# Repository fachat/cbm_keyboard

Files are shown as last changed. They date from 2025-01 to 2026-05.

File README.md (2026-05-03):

# Commodore PET keyboards

Note: this is a part of a larger set of repositories, with [upet_family](https://github.com/fachat/upet_family) as the main repository.

This is part of a re-incarnation of the Commodore PET computer(s) from the later 1970s.

This repo shows how to build a keyboard for the Commodore PET, mainly for my own re-incarnation, but potentially for original PET as well (untested).

Keyboards can be seen in the PETindex [keyboard section](http://www.6502.org/users/andre/petindex/keyboards.html).

## N-Type

This keyboard is the typewriter-stlye keyboard used in most 40 column models, except for the originals with the chicklet keyboard.

### PCB

#### Open source PCB by Steve Gray

For my builds I started by using the N-type keyboard PCB by Steve Gray from his [MX replacement keyboards projects](http://cbmsteve.ca/mxkeyboards/index.html)
As Steve only has the PCB, I designed a 3D-printable base support for the PCB.
It is available on tinkercad and the STL files are also available here.

Based on that I created a new R3 version of the board that includes options for
backlit LEDs and keyboard controllers allowing key re-mapping independent from
the PET's own editor ROM. You can find it in [PET-N](PET-N)

NOTE: In R3.0A you need to fix some things:

1. Connect the V33 and VCC33 lines - basically the oscillator for the Atmega controllers does not have power, so that needs to be supplied.
2. There is an off-by-one error on the row multiplexer. It has rows R0-9, while the keys are connected to R1-10. For now you have to connect R0 and R10, and fix the issue in the controller software.

In the current R3.0B these two fixes have been applied, but the actual PCB is not tested yet (and probably never will). A future 3.1 fix this for good.

### Programming the R3 PCB

The R3 PCB has (optionally) two Atmega32a microcontrollers on board, that implement two functions:

1. mapping keys between the keyboard and the host 
2. controlling the LEDs.

To program the Microcontrollers you need an AVR programming tool like the AVRisp MkII that I use, or similar, that can program via the SPI interface (plus Reset) on the 6 pin programming header (which exists separately for each of the two Microcontrollers)

Both microcontrollers are connected to the I2C bus on the extended UPET keyboard interface.

#### Functions of the keyboard controller

Currently the keyboard controller maps the keys 1:1 from the keyboard matrix to the host keyboard interface.

In addition it sends the pressed keys (hardware key index) via I2C to address 0x10 (which is the LED controller).

Also, the keyboard mapping has these options:

1. direct mapping - each key is directly mapped to the corresponding host key
2. The top row of characters is remapped from the PET-N's characters (like $, %, etc) to the digits you'd normally expect in this place. The original chars are available with Shift, the originally shifted characters are available with Ctrl.

Note that in the future more mappings may be implemented.

Selection of the mapping is done by pressing the SRQ key a few seconds long. The keyboard will then send a menu text to the host that instructs the user how to switch the mapping.
It is best if the menu is triggered e.g. on the BASIC prompt.

The mapping is stored in the Atmega's EEPROM, and thus retained when the machine is switched off.

#### Functions of the LED controller

The LED controller listens on the I2C address 0x10 for commands.

With these commands you can set the constant value of each key LED, but also trigger certain programs that involve either a single key, or multiple keys.
For single keys you can let the colour slowly get dimmer until the LED is off, and then optionally restart with the original value.

The DILUTE program tries to do a simulated flow of the colour from the given key to the surrounding keys. It is not as good and smooth as it could be as the 
Atmega lacks memory to store the required precision of colour values.

The LOGO just sends the logo onto the keypad, and then lets it decay.

```
        // single LED programs. Followed by index, three colours, and a parameter
        LP_CONST        = 0,    // constant value, using the three parameters as RGB
        LP_LINDECAY     = 1,    // linear decay (note may change hue while getting lower)
        LP_LINDECAYLOOP = 2,    // linear decay with restart

        // single command program
        SP_KEYPRESS     = 64,   // just followed by the index to indicate a pressed key

        // multi-key programs
        KP_DILUTE       = 128,  // set initial value to given params, then let it flow off 
        KP_LOGO         = 129,  // C= logo on the keypad
```

All commands except KEYPRESS expect the key index, three colours, and a parameter after the command, i.e. six bytes in total.
KEYPRESS only has the index and thus requires only two bytes.

### Supports for PCB

The PCB needs some kind of support to be mounted into the PET or the Ulti-/Micro-PET cases.
There are two versions for Steve's and my derived PCB, the first one for the extended
that caters for the different connector, and the one better suitable for the original
PCB.

* [New support structure extended PET-N keyboard](https://www.tinkercad.com/things/2KwSQVdno7K-sjg-keybd-full-support-r1)
* [left part of the support](PET-Keyboard-Support-SJG-N-R1-left.stl)
* [right part of the support](PET-Keyboard-Support-SJG-N-R1-right.stl)

* [support structure for Steve's N-type keyboard at tinkercad](https://www.tinkercad.com/things/cUVlushPB3j-sjg-keybd-full-support-v07).
* [left part of the support](PET-Keyboard-Support-SJG-N-v07-left.stl)
* [right part of the support](PET-Keyboard-Support-SJG-N-v07-right.stl)

#### Texelec Petskey keyboard

This is the PET N-type keyboard available from Texelec.

As this is the PCB only, I have created a support structure for this too. Note, however, as I now prefer Steve's PCB, I only have an old version of the supports on tinkercad.

Two of each of these supports make up a keyboard base plate, where you only need to clip in the PCB for the keyboard with the mounted key switches. Then they have about the same dimensions as a C64 keyboard, and you can use them on top of the C64 keyboard support stands.

* [Petskey 1.0 keyboard on Texelec](https://texelec.com/product/petskey/)
* [Petskey support on tinkercad](https://www.tinkercad.com/things/5lenSoehSRu-petskey-full-support-plate)

### Key caps

There are two options, either use standard key caps, or 3D-printed ones.

#### Standard Keycaps

As, for the self-built keyboards from option 1 or 2 some standard MX switches are used, standard
key caps can be used as well. There is one caveat, however.

Newer key caps typically have a different inclination for each row of keys, that is the angle of the top key surface against the horizontal
is different for each row. This is to facilitate easier typing. In fact even the C64 keyboard has this.
The old PET keyboards, however, have the same angle - which is not zero! - for all rows. This makes it easier to use the same cap (in terms of physical dimensions)
on all rows, and just print on a different character for each key. Read more on those [key profiles](https://switchandclick.com/sa-vs-dsa-vs-oem-vs-cherry-vs-xda-keycap-profiles/).

I used two type of standard key caps:

1. [XDA profile, unmarked](https://www.amazon.de/gp/product/B06XSHK528/): this set of key caps does not have a print on it, and all keys have the same angle - zero. So it is
possible to use any of the key caps in any row. Which is important, as you need a specific number of keys for each key width.
Also, this set has space bars in different lengths, and there is one that fits the 6.25 character wide space bar for the petskey and sjg keyboards.
For the markings I just used a pen...

2. This one [Glorious PC Gaming Race ABS Doubleshot black, ANSI layout GAKC-045](https://www.caseking.de/glorious-pc-gaming-race-abs-doubleshot-schwarz-ansi-us-layout-gakc-045.html) I actually bought more or less
by accident. I only noticed that it has different angles per row when I tried it out. However, with the amount of caps I was able to only
use a wrong angle on Shift Lock, left Shift, Return and "4" - but it's barely noticable.
For the markings I used template from Steve's page, printed it on sticky paper, cut it out and glued it on the keys where the original did not fit.

#### Printed Keycaps

As a third option I used 3-D printed key caps that I designed myself.

The keycaps are made of three parts each:
1) a key form created by a parametric generator,
2) the top character print, extruded from the key form,
3) the front character (mostly the shifted character), extruded from the key form.

I created all parts, and integrated them in the [Tinkercad](https://tinkercad.com) web tool.

The key form is created using OpenSCAD by a [parametric generator](https://www.thingiverse.com/thing:2783650) (by Thingieverse user rsheldiii, published under the [CC BY-SA 3.0](https://creativecommons.org/licenses/by-sa/3.0/) license). Here is the [parameter file](keycaps/key_cbm3_customizer.scad). Only the key width needs to be adapted, and the inversion of the top for the space key.

Most of the top character prints are made from a [Microgramm font](https://www.wfonts.com/font/microgramma), converted to SVG using the [Font Squirrel](https://www.fontsquirrel.com/tools/webfont-generator) web page.

Some top characters, and especially the top words ("SHIFT", "RUN STOP" etc) are taken from [Steve's github page](https://github.com/sjgray/CBM-MX-Keyboards/tree/master/stickers). As SVG exported from inkscape did not work when imported
into tinkercad, I had to make screenshots from each character, and convert these screenshots into SVGs using this [online converter](https://image.online-convert.com/convert-to-svg).

The front characters are all from an [SVG file from wikipedia](https://en.wikipedia.org/wiki/Commodore_PET#/media/File:PET_Keyboard_improved.svg), from which I also took screenshots and converted to SVG as above.

You can find an oder version of the the STL files [here](keycaps/), in four parts due to its size. The current version is linked from tinkercad below.
Please note that it took me about 100+ hours just to print the full set of keys on my Snapmaker printer in high quality.
After printing you have to remove the supports that anchor the stem to the outside of the keycaps so it does
not break away when printing.

For your convenience there is an open project at PCBWay to print the key caps, see the links.

* [Keycaps for resin printing](https://www.tinkercad.com/things/7a94wJbLJPW-commodore-pet-caps-for-n-type-ulti-keyboard-resin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)
* [Master file for keycaps](https://www.tinkercad.com/things/clKxMCUccgg-master-commodore-pet-caps-for-n-ulti-keyboard-support-cuts)
[//] # * [Open project at PCBWay 3D printing](https://www.pcbway.com/project/shareproject/Commodore_PET_N_type_keycaps_c1c2d1a0.html)

### Switches

The PCBs work with standard Cherry-type/-compatible switches. I only tested Cherry brand switches, though. You may select depending on your preference regarding force needed, click noise etc.

I found the MX1A-C1NW a good compromise for me.

* [Cherry MX1A-C1NW at Mouser](https://www.mouser.de/ProductDetail/540-MX1A-C1NW)

## Gallery

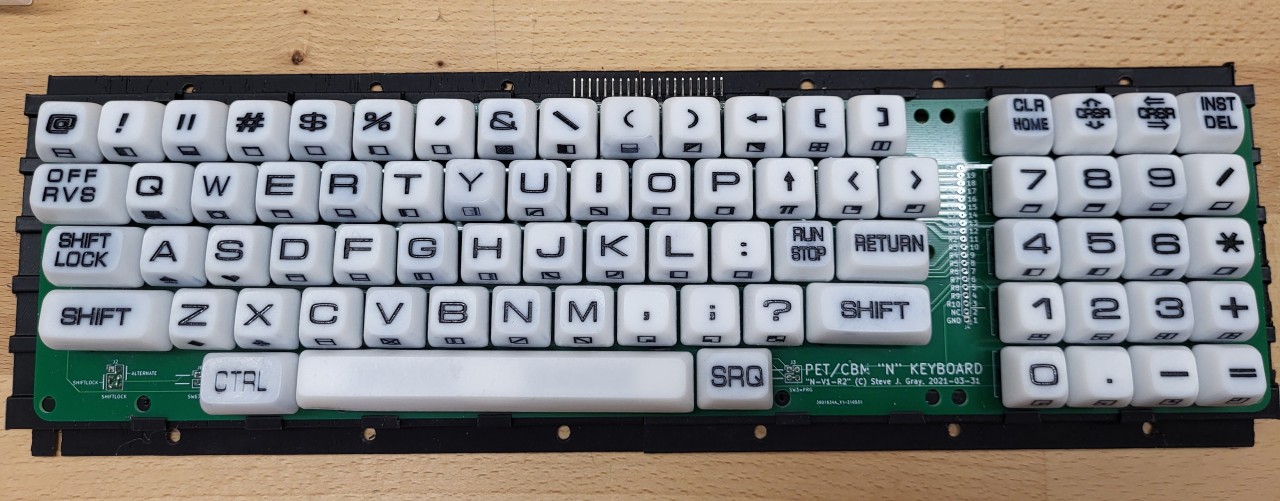
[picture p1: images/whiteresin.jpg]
Assembled keyboard with white resin printed caps
 Assembled keyboard with white resin printed caps, with key prints painted with black alcohol ink
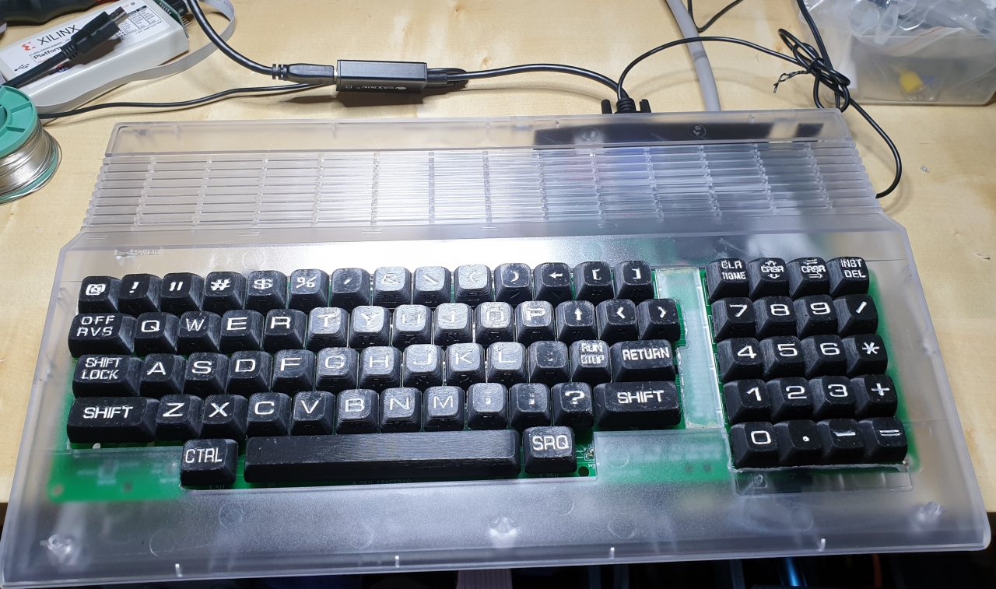
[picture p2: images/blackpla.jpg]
Assembled keyboard with black PLA printed caps
 Assembled keyboard with black PLA printed caps, with key prints painted with white alcohol ink
Assembled keyboard with black PLA printed caps Assembled keyboard with black PLA printed caps

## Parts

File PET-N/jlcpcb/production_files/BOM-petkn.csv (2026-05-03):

Comment | Designator | Footprint | LCSC | Quantity
100n | C10,C11,C12,C13,C14,C17,C30,C31,C7,C8,C9 | C_0805_2012Metric_Pad1.18x1.45mm_HandSolder | C14663 | 11
100u | C1,C15,C16,C18,C19,C2,C20,C21,C22,C23,C24,C25,C26,C27,C28,C29,C3,C32,C33,C4,C5,C6 | C_1206_3216Metric_Pad1.33x1.80mm_HandSolder | C15008 | 22
10k | R3,R4,R5 | R_0603_1608Metric | C25804 | 3
LSF0204Q | U1 | TSSOP-14_4.4x5mm_P0.65mm | C2677502 | 1
~ | U5 | THB Miniature Thumbstick THB001P | C2685355 | 1
2k2 | R1,R2 | R_0603_1608Metric | C4190 | 2
KP "=" | SW1,SW10,SW11,SW12,SW14,SW15,SW16,SW17,SW18,SW2,SW20,SW21,SW22,SW23,SW24,SW25,SW26,SW27,SW28,SW29,SW3,SW30,SW31,SW32,SW320,SW33,SW34,SW36,SW37,SW38,SW39,SW4,SW40,SW41,SW42,SW44,SW45,SW46,SW47,SW48,SW49,SW5,SW50,SW52,SW53,SW54,SW55,SW56,SW57,SW58,SW59,SW6,SW60,SW61,SW62,SW63,SW64,SW65,SW66,SW67,SW68,SW69,SW7,SW70,SW71,SW72,SW73,SW74,SW75,SW76,SW77,SW78,SW79,SW8,SW80,SW9 | SW_Cherry_MX_1.00u_PCB_with_RGB_LED | C5149201 | 76
ASE-xxxMHz | Y1 | Oscillator_SMD_Abracon_ASE-4Pin_3.2x2.5mm | C5158780 | 1
AVR-ISP-6 | J4,J7 | IDC-Header_2x03_P2.54mm_Vertical | C5372863 | 2
ATmega32A-A | U2,U8 | TQFP-44_10x10mm_P0.8mm | C5659 | 2
74HCT85 | U3 | SO-16_3.9x9.9mm_P1.27mm | C5953 | 1
74LS145 | U7 | SO-16_3.9x9.9mm_P1.27mm | C60829 | 1
74HCT00 | U9 | SOIC-14_3.9x8.7mm_P1.27mm | C6764 | 1
74LS174 | U4,U6 | SO-16_3.9x9.9mm_P1.27mm | C6828 | 2
1N4448 | D1,D10,D11,D12,D13,D14,D15,D16,D17,D18,D19,D2,D20,D21,D22,D23,D24,D25,D26,D27,D28,D29,D3,D30,D31,D32,D33,D34,D35,D36,D37,D38,D39,D4,D40,D41,D42,D43,D44,D45,D46,D47,D48,D49,D5,D50,D51,D52,D53,D54,D55,D56,D57,D58,D59,D6,D60,D61,D62,D63,D64,D65,D66,D67,D68,D69,D7,D70,D71,D72,D73,D74,D75,D76,D77,D78,D79,D8,D80,D81,D9 | D_SOD-323_HandSoldering | C8602 | 81
Extended_PET_keyboard_connector | J1 | PET_Extended_Keyboard_Connector |  | 1

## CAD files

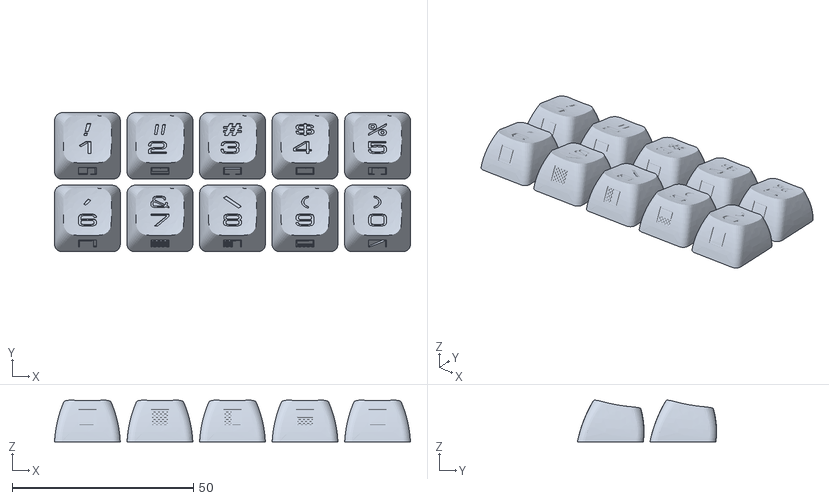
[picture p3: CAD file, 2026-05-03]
keycaps/Commodore PET caps for N-type Ulti keyboard resin pt1.stl
98.2 x 38.4 x 11.5

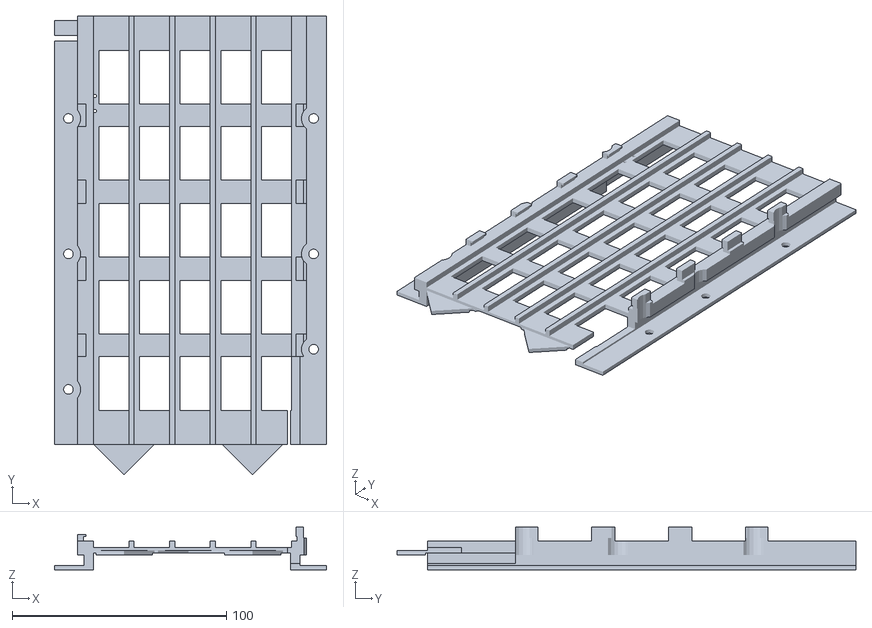
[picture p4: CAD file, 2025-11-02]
supports/PET-Keyboard-Support-SJG-N-R1 left.stl
127.0 x 214.1 x 20.0

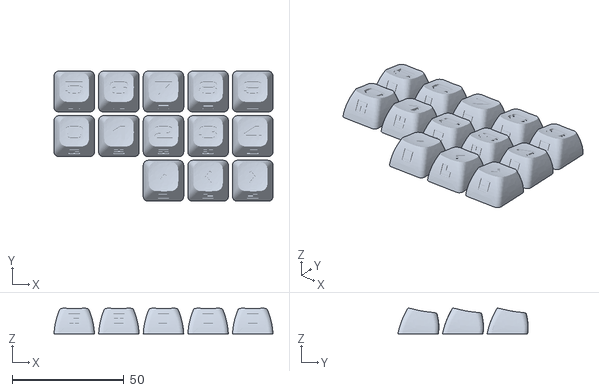
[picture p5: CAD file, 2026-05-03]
keycaps/Commodore PET caps for N-type Ulti keyboard resin pt2.stl
98.2 x 58.4 x 11.5

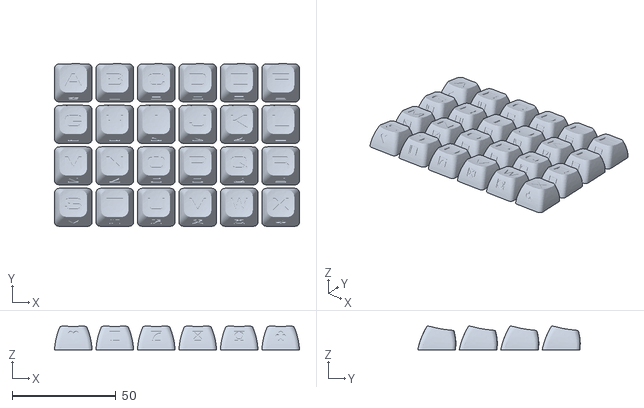
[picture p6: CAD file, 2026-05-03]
keycaps/Commodore PET caps for N-type Ulti keyboard resin pt4.stl
118.2 x 78.4 x 11.5

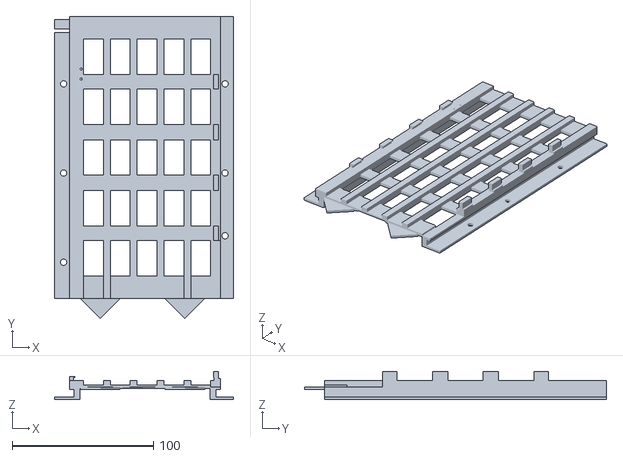
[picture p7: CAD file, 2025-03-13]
supports/PET-Keyboard-Support-SJG-N-v07-left.stl
127.0 x 214.1 x 20.0

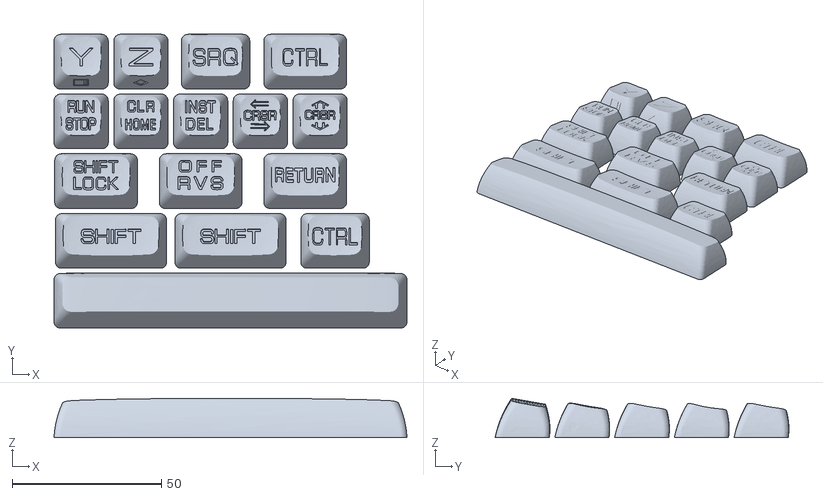
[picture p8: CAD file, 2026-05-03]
keycaps/Commodore PET caps for N-type Ulti keyboard resin pt5.stl
118.2 x 98.4 x 13.2

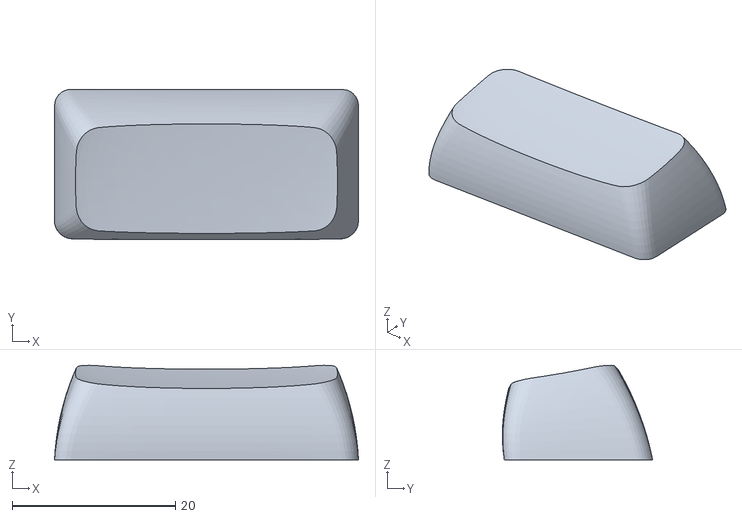
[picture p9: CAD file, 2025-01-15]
keycaps/key_cbm3_w2.0.stl
37.2 x 18.4 x 11.6

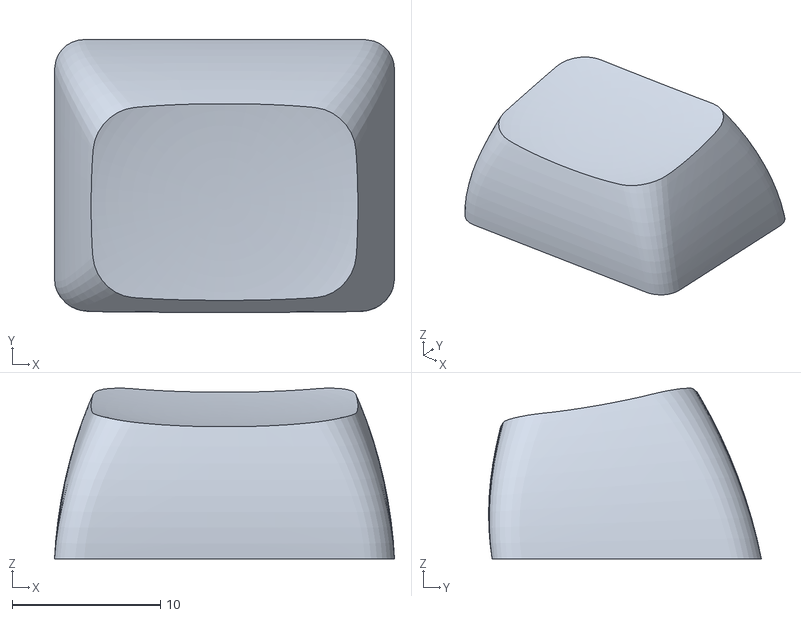
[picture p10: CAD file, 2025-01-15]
keycaps/key_cbm3_w1.25.stl
22.9 x 18.4 x 11.5

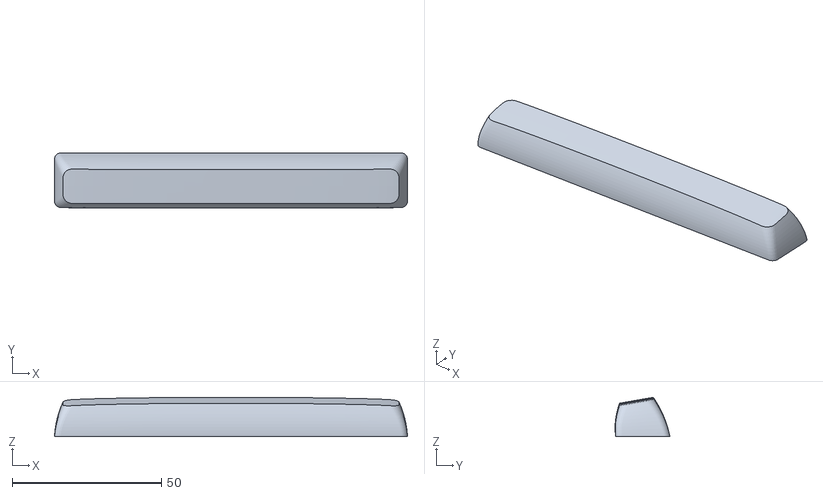
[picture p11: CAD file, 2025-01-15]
keycaps/key_cbm3_s6.25.stl
118.2 x 18.4 x 13.2

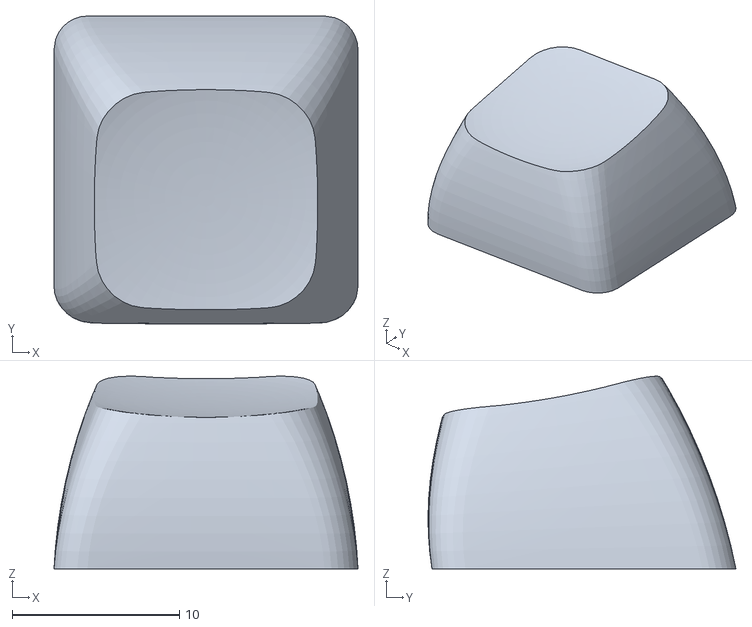
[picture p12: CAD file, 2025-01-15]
keycaps/key_cbm3_w1.0.stl
18.2 x 18.4 x 11.5

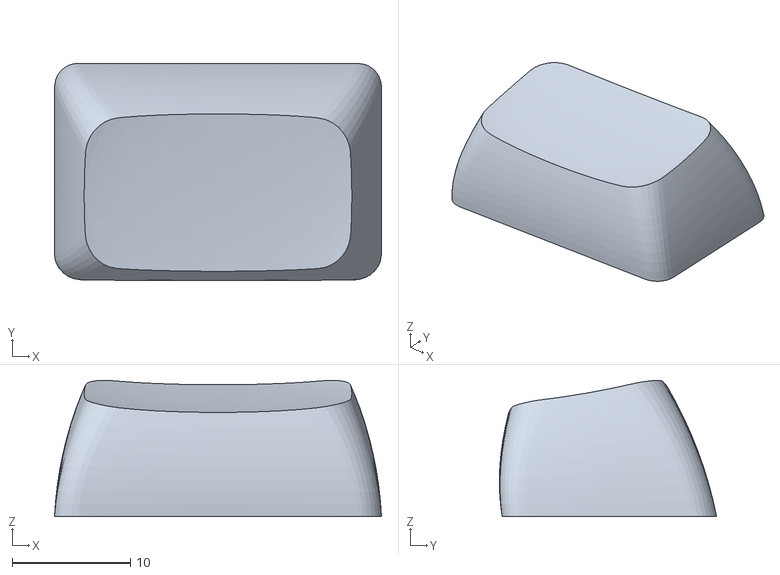
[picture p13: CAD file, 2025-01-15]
keycaps/key_cbm3_w1.5.stl
27.7 x 18.4 x 11.5

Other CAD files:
supports/PET-Keyboard-Support-SJG-N-R1 right.stl
keycaps/Commodore PET caps for N-type Ulti keyboard resin pt3.stl
supports/PET-Keyboard-Support-SJG-N-v07-right.stl
keycaps/key_cbm3_customizer.scad

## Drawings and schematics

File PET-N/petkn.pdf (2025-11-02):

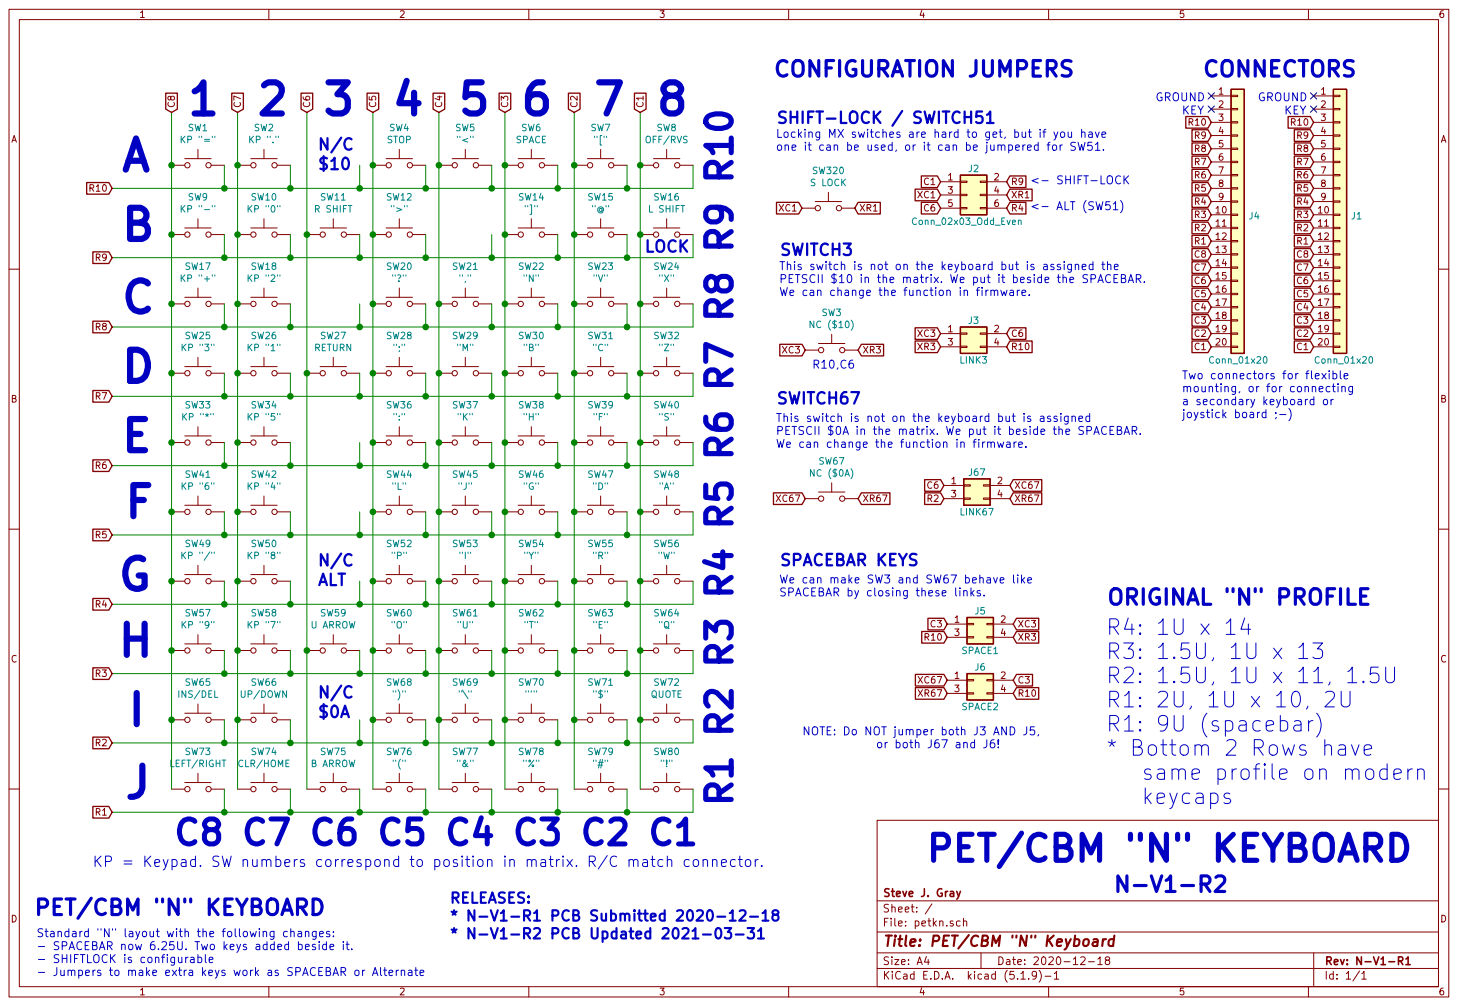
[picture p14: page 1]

SHIFT-LOCK / SWITCH51
Locking MX switches are hard to get, but if you have
one it can be used, or it can be jumpered for SW51.

SWITCH3
This switch is not on the keyboard but is assigned the
PETSCII $10 in the matrix. We put it beside the SPACEBAR.
We can change the function in firmware.

SWITCH67
This switch is not on the keyboard but is assigned
PETSCII $0A in the matrix. We put it beside the SPACEBAR.

Two connectors for flexible
mounting, or for connecting
a secondary keyboard or
joystick board ;-)

SPACEBAR KEYS
We can make SW3 and SW67 behave like
SPACEBAR by closing these links.

SW60 "O" SW59 U ARROW

NOTE: Do NOT jumper both J3 AND J5,
or both J67 and J6!

LEFT/RIGHT

KP = Keypad. SW numbers correspond to position in matrix. R/C match connector.
PET/CBM "N" KEYBOARD
Standard "N" layout with the following changes:
- SPACEBAR now 6.25U. Two keys added beside it.
- SHIFTLOCK is configurable
- Jumpers to make extra keys work as SPACEBAR or Alternate

File: petkn.sch Sheet: / Steve J. Gray

Id: 1/1 Title: PET/CBM "N" Keyboard

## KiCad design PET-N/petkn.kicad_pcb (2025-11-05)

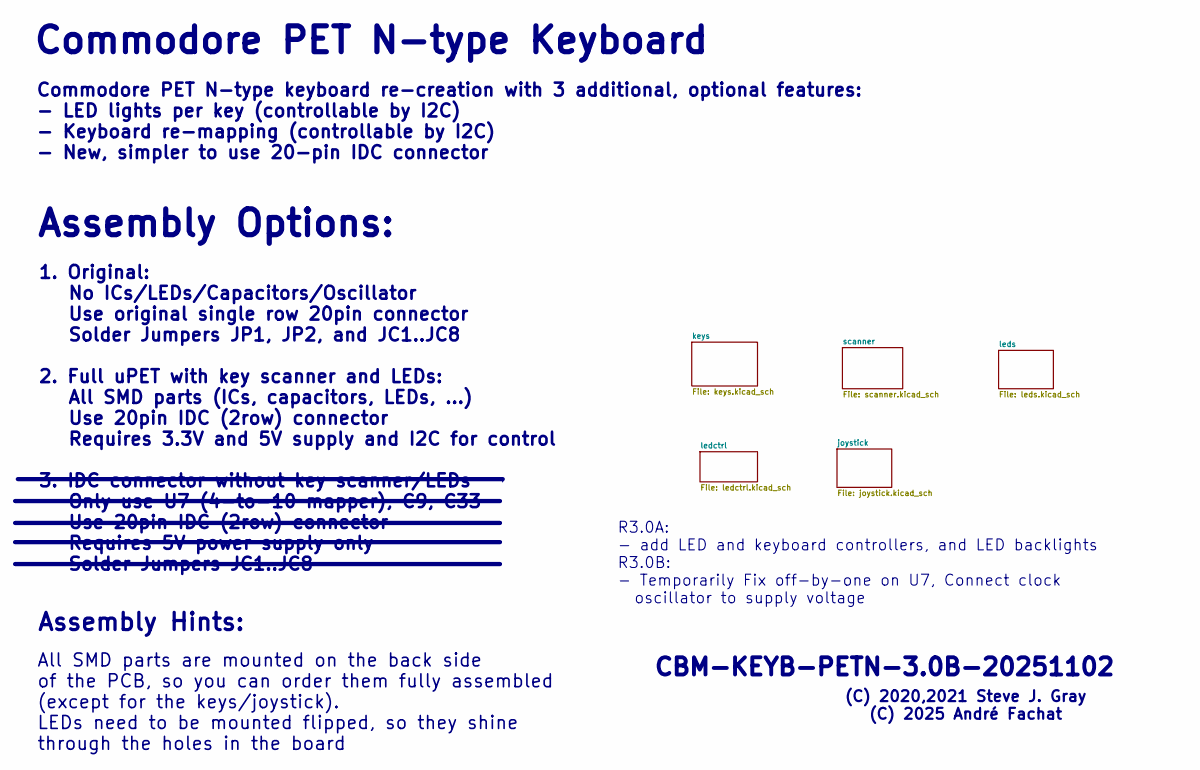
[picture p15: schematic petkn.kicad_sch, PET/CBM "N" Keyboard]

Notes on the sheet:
1. Original: No ICs/LEDs/Capacitors/Oscillator Use original single row 20pin connector Solder Jumpers JP1, JP2, and JC1..JC8 2. Full uPET with key scanner and LEDs: All SMD parts (ICs, capacitors, LEDs, ...) Use 20pin IDC (2row) connector Requires 3.3V and 5V supply and I2C for control 3. IDC conne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
R3.0A: - add LED and keyboard controllers, and LED backlights R3.0B: - Temporarily Fix off-by-one on U7, Connect clock oscillator to supply voltage
All SMD parts are mounted on the back side of the PCB, so you can order them fully assembled (except for the keys/joystick). LEDs need to be mounted flipped, so they shine through the holes in the board
Commodore PET N-type keyboard re-creation with 3 additional, optional features: - LED lights per key (controllable by I2C) - Keyboard re-mapping (controllable by I2C) - New, simpler to use 20-pin IDC connector
Assembly Options:
(C) 2020,2021 Steve J. Gray (C) 2025 André Fachat
Assembly Hints:
Commodore PET N-type Keyboard
CBM-KEYB-PETN-3.0B-20251102

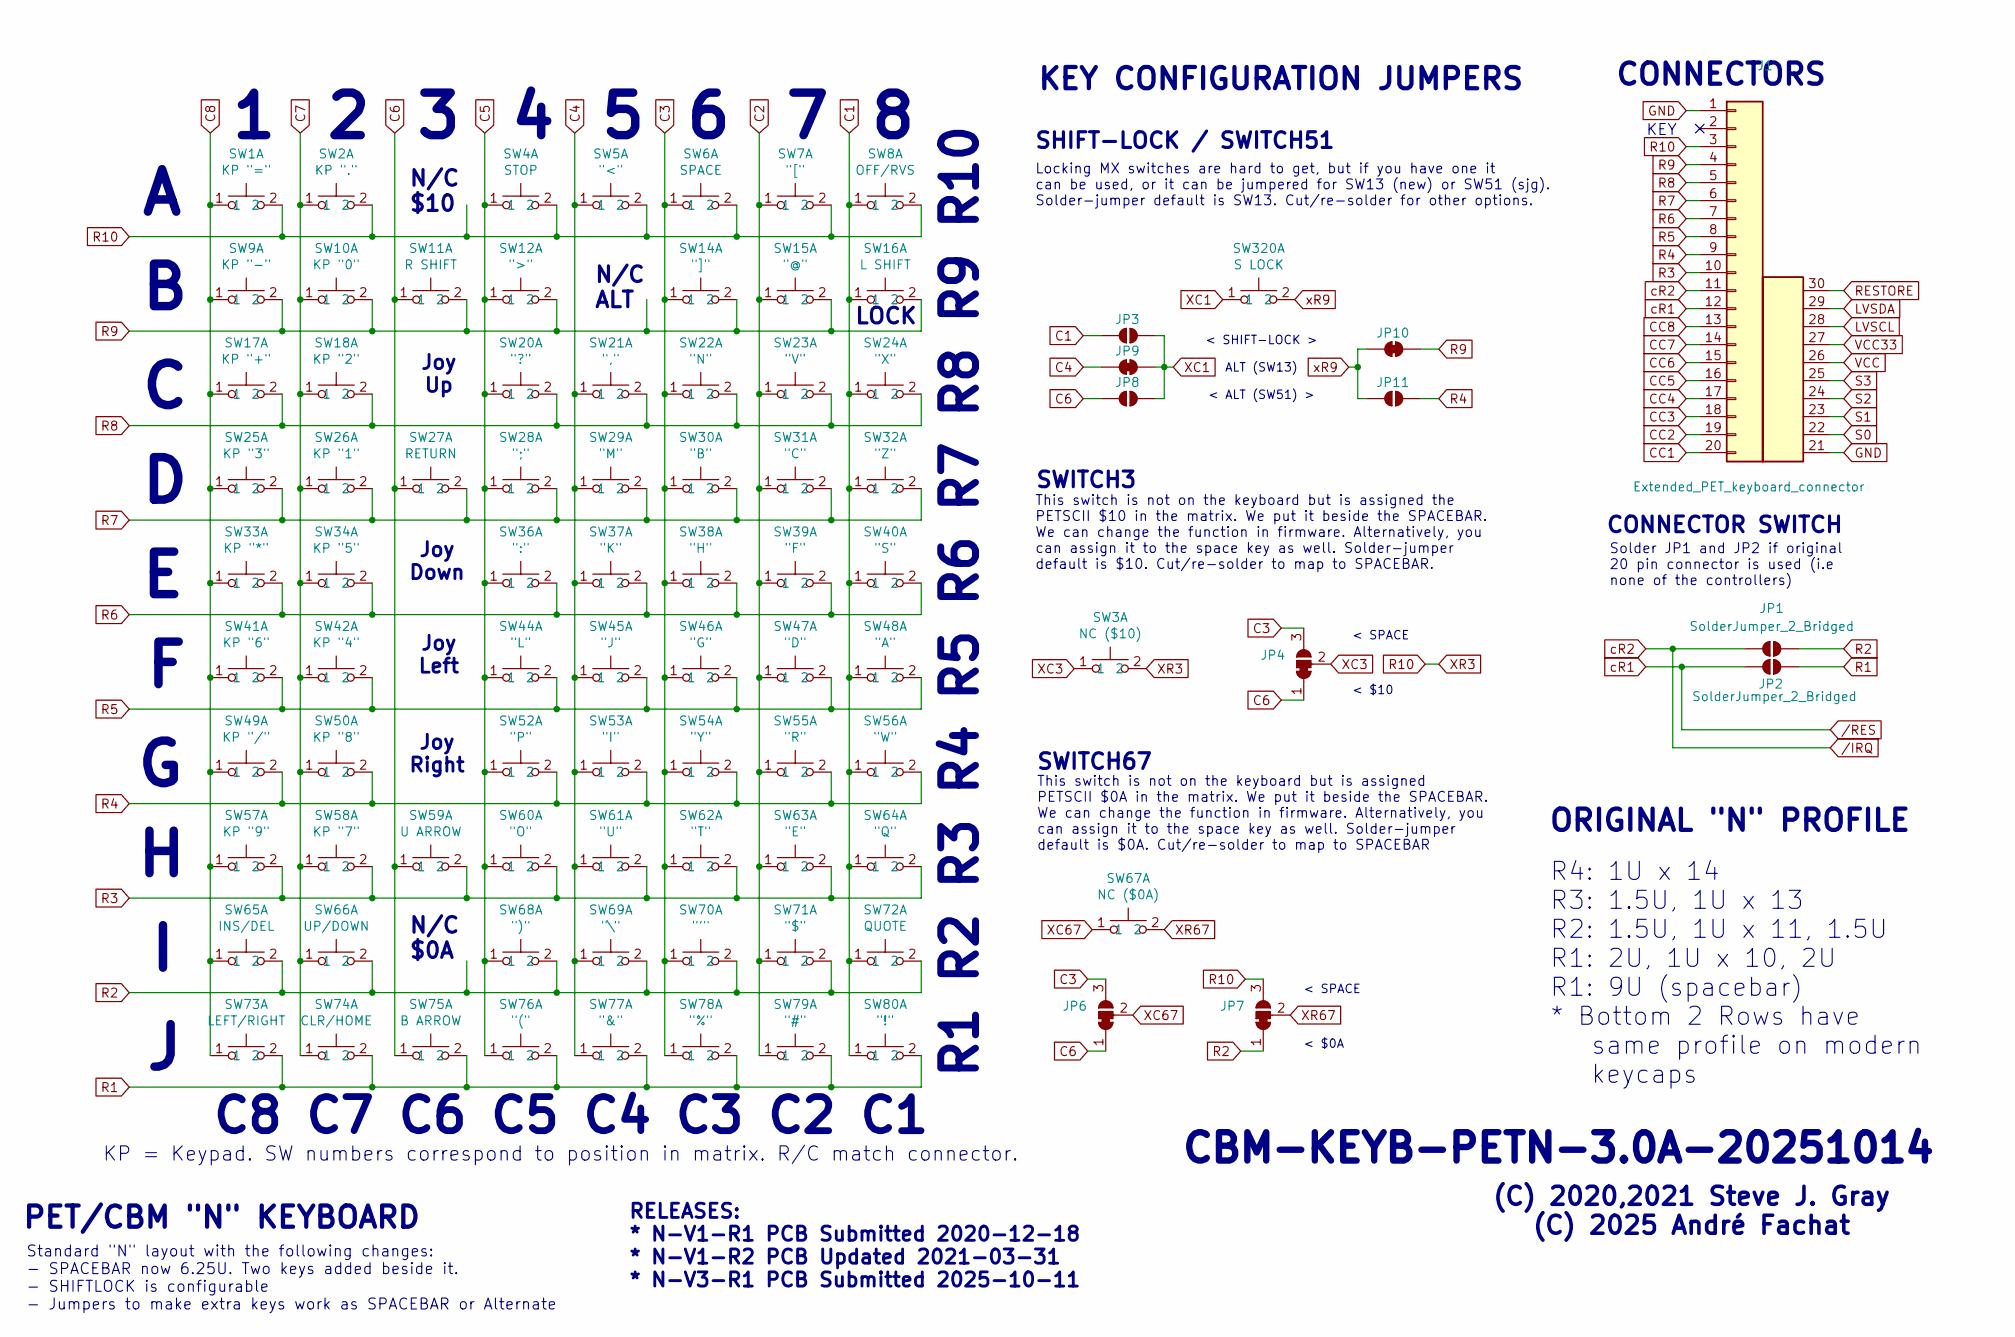
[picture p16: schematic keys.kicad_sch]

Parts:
J1: Extended_PET_keyboard_connector; PET_Extended_Keyboard_Connector
JP1, JP2, JP3, JP8, JP11: SolderJumper_2_Bridged; SolderJumper-2_P1.3mm_Open_RoundedPad1.0x1.5mm
JP4, JP6, JP7: SolderJumper_3_Bridged12; SolderJumper-3_P1.3mm_Bridged12_RoundedPad1.0x1.5mm_NumberL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
JP9, JP10: SolderJumper_2_Bridged; SolderJumper-2_P1.3mm_Bridged_RoundedPad1.0x1.5mm
SW1: KP "="; SW_Cherry_MX_1.00u_PCB_with_RGB_LED
SW2: KP "."; SW_Cherry_MX_1.00u_PCB_with_RGB_LED
SW3: NC ($10); SW_Cherry_MX_1.25u_PCB_with_RGB_LED
SW4: STOP; SW_Cherry_MX_1.00u_PCB_with_RGB_LED
SW5: "<"; SW_Cherry_MX_1.00u_PCB_with_RGB_LED
SW6: SPACE; SW_Cherry_MX_6.25u_PCB_with_RGB_LED
SW7: "["; SW_Cherry_MX_1.00u_PCB_with_RGB_LED
SW8: OFF/RVS; SW_Cherry_MX_1.50u_PCB_with_RGB_LED
SW9: KP "-"; SW_Cherry_MX_1.00u_PCB_with_RGB_LED
SW10: KP "0"; SW_Cherry_MX_1.00u_PCB_with_RGB_LED
SW11: R SHIFT; SW_Cherry_MX_2.00u_PCB_with_RGB_LED
SW12: ">"; SW_Cherry_MX_1.00u_PCB_with_RGB_LED
SW14: "]"; SW_Cherry_MX_1.00u_PCB_with_RGB_LED
SW15: "@"; SW_Cherry_MX_1.00u_PCB_with_RGB_LED
SW16: L SHIFT; SW_Cherry_MX_2.00u_PCB_with_RGB_LED
SW17: KP "+"; SW_Cherry_MX_1.00u_PCB_with_RGB_LED
SW18: KP "2"; SW_Cherry_MX_1.00u_PCB_with_RGB_LED
SW20: "?"; SW_Cherry_MX_1.00u_PCB_with_RGB_LED
SW21: ","; SW_Cherry_MX_1.00u_PCB_with_RGB_LED
SW22: "N"; SW_Cherry_MX_1.00u_PCB_with_RGB_LED
SW23: "V"; SW_Cherry_MX_1.00u_PCB_with_RGB_LED
SW24: "X"; SW_Cherry_MX_1.00u_PCB_with_RGB_LED
SW25: KP "3"; SW_Cherry_MX_1.00u_PCB_with_RGB_LED
SW26: KP "1"; SW_Cherry_MX_1.00u_PCB_with_RGB_LED
SW27: RETURN; SW_Cherry_MX_1.50u_PCB_with_RGB_LED
SW28: ";"; SW_Cherry_MX_1.00u_PCB_with_RGB_LED
SW29: "M"; SW_Cherry_MX_1.00u_PCB_with_RGB_LED
SW30: "B"; SW_Cherry_MX_1.00u_PCB_with_RGB_LED
SW31: "C"; SW_Cherry_MX_1.00u_PCB_with_RGB_LED
SW32: "Z"; SW_Cherry_MX_1.00u_PCB_with_RGB_LED
SW33: KP "*"; SW_Cherry_MX_1.00u_PCB_with_RGB_LED
SW34: KP "5"; SW_Cherry_MX_1.00u_PCB_with_RGB_LED
SW36: ":"; SW_Cherry_MX_1.00u_PCB_with_RGB_LED
SW37: "K"; SW_Cherry_MX_1.00u_PCB_with_RGB_LED
SW38: "H"; SW_Cherry_MX_1.00u_PCB_with_RGB_LED
SW39: "F"; SW_Cherry_MX_1.00u_PCB_with_RGB_LED
SW40: "S"; SW_Cherry_MX_1.00u_PCB_with_RGB_LED
SW41: KP "6"; SW_Cherry_MX_1.00u_PCB_with_RGB_LED
SW42: KP "4"; SW_Cherry_MX_1.00u_PCB_with_RGB_LED
SW44: "L"; SW_Cherry_MX_1.00u_PCB_with_RGB_LED
SW45: "J"; SW_Cherry_MX_1.00u_PCB_with_RGB_LED
SW46: "G"; SW_Cherry_MX_1.00u_PCB_with_RGB_LED
SW47: "D"; SW_Cherry_MX_1.00u_PCB_with_RGB_LED
SW48: "A"; SW_Cherry_MX_1.00u_PCB_with_RGB_LED
SW49: KP "/"; SW_Cherry_MX_1.00u_PCB_with_RGB_LED
SW50: KP "8"; SW_Cherry_MX_1.00u_PCB_with_RGB_LED
SW52: "P"; SW_Cherry_MX_1.00u_PCB_with_RGB_LED
SW53: "I"; SW_Cherry_MX_1.00u_PCB_with_RGB_LED
SW54: "Y"; SW_Cherry_MX_1.00u_PCB_with_RGB_LED
SW55: "R"; SW_Cherry_MX_1.00u_PCB_with_RGB_LED
SW56: "W"; SW_Cherry_MX_1.00u_PCB_with_RGB_LED
SW57: KP "9"; SW_Cherry_MX_1.00u_PCB_with_RGB_LED
SW58: KP "7"; SW_Cherry_MX_1.00u_PCB_with_RGB_LED
SW59: U ARROW; SW_Cherry_MX_1.00u_PCB_with_RGB_LED
SW60: "O"; SW_Cherry_MX_1.00u_PCB_with_RGB_LED
SW61: "U"; SW_Cherry_MX_1.00u_PCB_with_RGB_LED
SW62: "T"; SW_Cherry_MX_1.00u_PCB_with_RGB_LED
SW63: "E"; SW_Cherry_MX_1.00u_PCB_with_RGB_LED
SW64: "Q"; SW_Cherry_MX_1.00u_PCB_with_RGB_LED
SW65: INS/DEL; SW_Cherry_MX_1.00u_PCB_with_RGB_LED
SW66: UP/DOWN; SW_Cherry_MX_1.00u_PCB_with_RGB_LED
SW67: NC ($0A); SW_Cherry_MX_1.50u_PCB_with_RGB_LED
SW68: ")"; SW_Cherry_MX_1.00u_PCB_with_RGB_LED
SW69: "\"; SW_Cherry_MX_1.00u_PCB_with_RGB_LED
SW70: "'"; SW_Cherry_MX_1.00u_PCB_with_RGB_LED
SW71: "$"; SW_Cherry_MX_1.00u_PCB_with_RGB_LED
SW72: QUOTE; SW_Cherry_MX_1.00u_PCB_with_RGB_LED
SW73: LEFT/RIGHT; SW_Cherry_MX_1.00u_PCB_with_RGB_LED
SW74: CLR/HOME; SW_Cherry_MX_1.00u_PCB_with_RGB_LED
SW75: B ARROW; SW_Cherry_MX_1.00u_PCB_with_RGB_LED
SW76: "("; SW_Cherry_MX_1.00u_PCB_with_RGB_LED
SW77: "&"; SW_Cherry_MX_1.00u_PCB_with_RGB_LED
SW78: "%"; SW_Cherry_MX_1.00u_PCB_with_RGB_LED
SW79: "#"; SW_Cherry_MX_1.00u_PCB_with_RGB_LED
SW80: "!"; SW_Cherry_MX_1.00u_PCB_with_RGB_LED
SW320: S LOCK; SW_Cherry_MX_1.50u_PCB_with_RGB_LED

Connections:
C1: JP3.1 (A), SW8.1, SW16.1, SW24.1, SW32.1, SW40.1, SW48.1, SW56.1, SW64.1, SW72.1, SW80.1; also elsewhere on the board
C2: SW7.1, SW15.1, SW23.1, SW31.1, SW39.1, SW47.1, SW55.1, SW63.1, SW71.1, SW79.1; also elsewhere on the board
C3: JP4.3 (B), JP6.3 (B), SW6.1, SW14.1, SW22.1, SW30.1, SW38.1, SW46.1, SW54.1, SW62.1, SW70.1, SW78.1; also elsewhere on the board
C4: JP9.1 (A), SW5.1, SW21.1, SW29.1, SW37.1, SW45.1, SW53.1, SW61.1, SW69.1, SW77.1; also elsewhere on the board
C5: SW4.1, SW12.1, SW20.1, SW28.1, SW36.1, SW44.1, SW52.1, SW60.1, SW68.1, SW76.1; also elsewhere on the board
C6: JP4.1 (A), JP6.1 (A), JP8.1 (A), SW11.1, SW27.1, SW59.1, SW75.1; also elsewhere on the board
C7: SW2.1, SW10.1, SW18.1, SW26.1, SW34.1, SW42.1, SW50.1, SW58.1, SW66.1, SW74.1; also elsewhere on the board
C8: SW1.1, SW9.1, SW17.1, SW25.1, SW33.1, SW41.1, SW49.1, SW57.1, SW65.1, SW73.1; also elsewhere on the board
CC1: J1.20 (C1); also elsewhere on the board
CC2: J1.19 (C2); also elsewhere on the board
CC3: J1.18 (C3); also elsewhere on the board
CC4: J1.17 (C4); also elsewhere on the board
CC5: J1.16 (C5); also elsewhere on the board
CC6: J1.15 (C6); also elsewhere on the board
CC7: J1.14 (C7); also elsewhere on the board
CC8: J1.13 (C8); also elsewhere on the board
GND: J1.1 (GND), J1.21 (GND); also elsewhere on the board
LVSCL: J1.28 (SCL); also elsewhere on the board
LVSDA: J1.29 (SCA); also elsewhere on the board
R1: JP2.2 (B), SW73.2, SW74.2, SW75.2, SW76.2, SW77.2, SW78.2, SW79.2, SW80.2; also elsewhere on the board
R2: JP1.2 (B), JP7.1 (A), SW65.2, SW66.2, SW68.2, SW69.2, SW70.2, SW71.2, SW72.2; also elsewhere on the board
R3: J1.10 (R3), SW57.2, SW58.2, SW59.2, SW60.2, SW61.2, SW62.2, SW63.2, SW64.2; also elsewhere on the board
R4: J1.9 (R4), JP11.2 (B), SW49.2, SW50.2, SW52.2, SW53.2, SW54.2, SW55.2, SW56.2; also elsewhere on the board
R5: J1.8 (R5), SW41.2, SW42.2, SW44.2, SW45.2, SW46.2, SW47.2, SW48.2; also elsewhere on the board
R6: J1.7 (R6), SW33.2, SW34.2, SW36.2, SW37.2, SW38.2, SW39.2, SW40.2; also elsewhere on the board
R7: J1.6 (R7), SW25.2, SW26.2, SW27.2, SW28.2, SW29.2, SW30.2, SW31.2, SW32.2; also elsewhere on the board
R8: J1.5 (R8), SW17.2, SW18.2, SW20.2, SW21.2, SW22.2, SW23.2, SW24.2; also elsewhere on the board
R9: J1.4 (R9), JP10.2 (B), SW9.2, SW10.2, SW11.2, SW12.2, SW14.2, SW15.2, SW16.2; also elsewhere on the board
R10: J1.3 (R10), JP7.3 (B), SW1.2, SW2.2, SW3.2, SW4.2, SW5.2, SW6.2, SW7.2, SW8.2; also elsewhere on the board
RESTORE: J1.30 (RESTORE)
S0: J1.22 (S0); also elsewhere on the board
S1: J1.23 (S1); also elsewhere on the board
S2: J1.24 (S2); also elsewhere on the board
S3: J1.25 (S3); also elsewhere on the board
VCC: J1.26 (VCC5); also elsewhere on the board
VCC33: J1.27 (VCC33); also elsewhere on the board
XC1: JP3.2 (B), JP8.2 (B), JP9.2 (B), SW320.1
XC3: JP4.2 (C), SW3.1
XC67: JP6.2 (C), SW67.1
XR67: JP7.2 (C), SW67.2
cR1: J1.12 (R1), JP2.1 (A); also elsewhere on the board
cR2: J1.11 (R2), JP1.1 (A)
xR9: JP10.1 (A), JP11.1 (A), SW320.2

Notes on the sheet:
PET/CBM "N" KEYBOARD
CONNECTORS
R1 R2 R3 R4 R5 R6 R7 R8 R9 R10
KEY CONFIGURATION JUMPERS
Locking MX switches are hard to get, but if you have one it can be used, or it can be jumpered for SW13 (new) or SW51 (sjg). Solder-jumper default is SW13. Cut/re-solder for other options.
Joy Up
RELEASES: * N-V1-R1 PCB Submitted 2020-12-18 * N-V1-R2 PCB Updated 2021-03-31 * N-V3-R1 PCB Submitted 2025-10-11
< SPACE < $0A
SWITCH3
Standard "N" layout with the following changes: - SPACEBAR now 6.25U. Two keys added beside it. - SHIFTLOCK is configurable - Jumpers to make extra keys work as SPACEBAR or Alternate
Solder JP1 and JP2 if original 20 pin connector is used (i.e none of the controllers)
< SPACE < $10
KEY
ORIGINAL "N" PROFILE
R4: 1U x 14 R3: 1.5U, 1U x 13 R2: 1.5U, 1U x 11, 1.5U R1: 2U, 1U x 10, 2U R1: 9U (spacebar) * Bottom 2 Rows have same profile on modern keycaps
KP = Keypad. SW numbers correspond to position in matrix. R/C match connector.
CBM-KEYB-PETN-3.0A-20251014
Joy Right
LOCK
< SHIFT-LOCK > ALT (SW13) < ALT (SW51) >
C8 C7 C6 C5 C4 C3 C2 C1
This switch is not on the keyboard but is assigned the PETSCII $10 in the matrix. We put it beside the SPACEBAR. We can change the function in firmware. Alternatively, you can assign it to the space key as well. Solder-jumper default is $10. Cut/re-solder to map to SPACEBAR.
Joy Down
(C) 2020,2021 Steve J. Gray (C) 2025 André Fachat
SWITCH67
Joy Left
N/C $0A
CONNECTOR SWITCH
N/C $10
SHIFT-LOCK / SWITCH51
This switch is not on the keyboard but is assigned PETSCII $0A in the matrix. We put it beside the SPACEBAR. We can change the function in firmware. Alternatively, you can assign it to the space key as well. Solder-jumper default is $0A. Cut/re-solder to map to SPACEBAR
N/C ALT

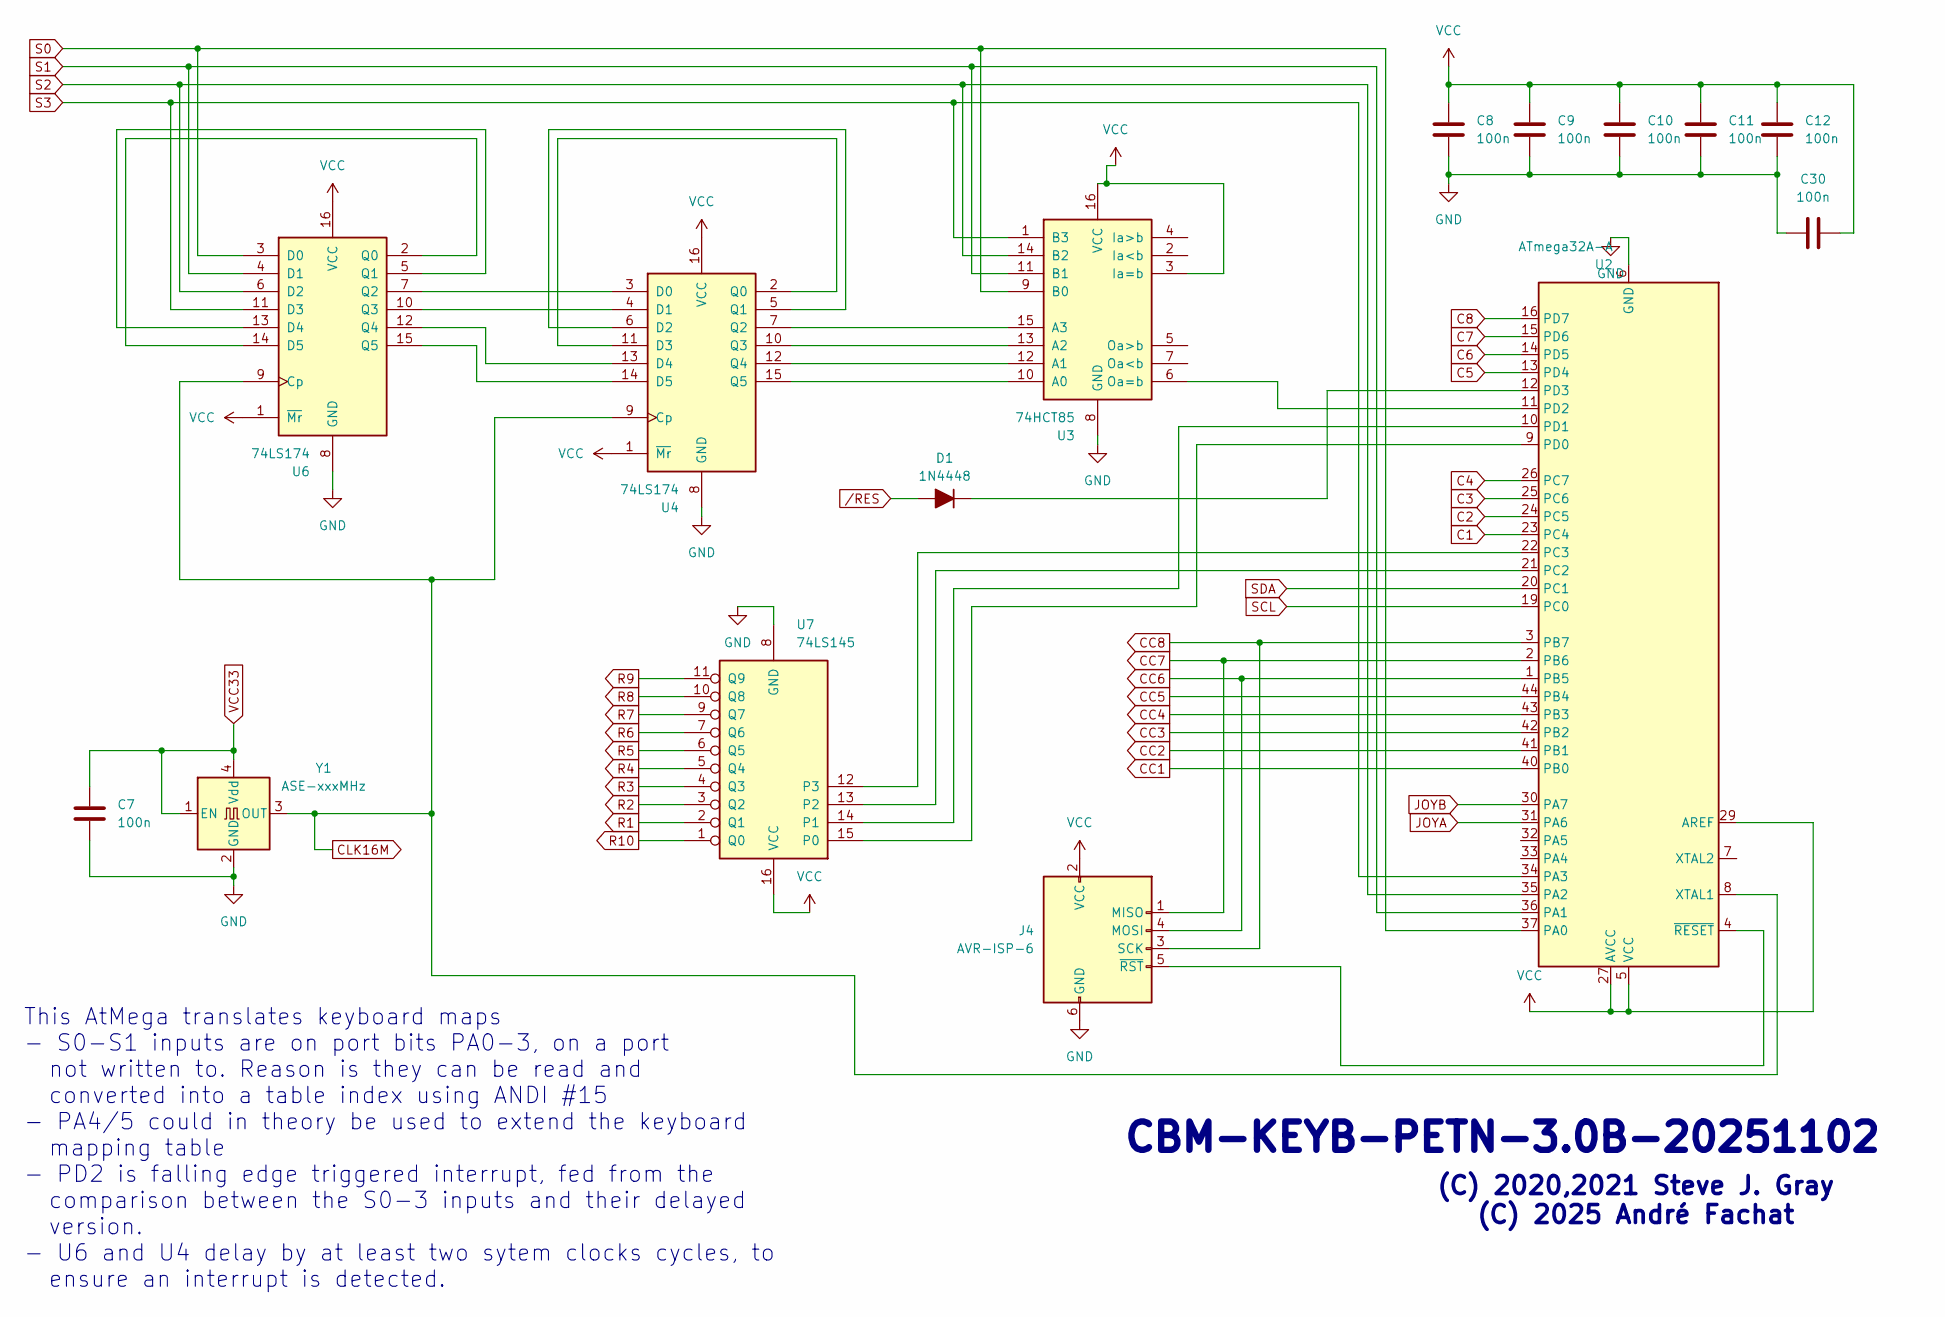
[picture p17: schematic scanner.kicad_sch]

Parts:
C7, C8, C9, C10, C11, C12, C30: 100n; C_0805_2012Metric_Pad1.18x1.45mm_HandSolder; LCSC C14663
D1: 1N4448; D_SOD-323_HandSoldering
J4: AVR-ISP-6; IDC-Header_2x03_P2.54mm_Vertical; LCSC C5372863
U2: ATmega32A-A; TQFP-44_10x10mm_P0.8mm; LCSC C5659
U3: 74HCT85; SO-16_3.9x9.9mm_P1.27mm; LCSC C5953
U4, U6: 74LS174; SO-16_3.9x9.9mm_P1.27mm; LCSC C6828
U7: 74LS145; SO-16_3.9x9.9mm_P1.27mm; LCSC C60829
Y1: ASE-xxxMHz; Oscillator_SMD_Abracon_ASE-4Pin_3.2x2.5mm; LCSC C12668

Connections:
C1: U2.23 (PC4); also elsewhere on the board
C2: U2.24 (PC5); also elsewhere on the board
C3: U2.25 (PC6); also elsewhere on the board
C4: U2.26 (PC7); also elsewhere on the board
C5: U2.13 (PD4); also elsewhere on the board
C6: U2.14 (PD5); also elsewhere on the board
C7: U2.15 (PD6); also elsewhere on the board
C8: U2.16 (PD7); also elsewhere on the board
CC1: U2.40 (PB0); also elsewhere on the board
CC2: U2.41 (PB1); also elsewhere on the board
CC3: U2.42 (PB2); also elsewhere on the board
CC4: U2.43 (PB3); also elsewhere on the board
CC5: U2.44 (PB4); also elsewhere on the board
CC6: J4.4 (MOSI), U2.1 (PB5); also elsewhere on the board
CC7: J4.1 (MISO), U2.2 (PB6); also elsewhere on the board
CC8: J4.3 (SCK), U2.3 (PB7); also elsewhere on the board
CLK16M: U2.8 (XTAL1), U4.9 (Cp), U6.9 (Cp), Y1.3 (OUT); also elsewhere on the board
GND: C7.2, C8.2, C9.2, C10.2, C11.2, C12.2, C30.1, J4.6 (GND), U2.6 (GND), U2.18 (GND), U2.28 (GND), U2.39 (GND), U3.8 (GND), U4.8 (GND), U6.8 (GND), U7.8 (GND), Y1.2 (GND); also elsewhere on the board
JOYA: U2.31 (PA6); also elsewhere on the board
JOYB: U2.30 (PA7); also elsewhere on the board
unnamed: D1.1 (K), U2.12 (PD3)
unnamed: J4.5 (~RST), U2.4 (~RESET)
unnamed: U2.21 (PC2), U7.13 (P2)
unnamed: U2.22 (PC3), U7.12 (P3)
unnamed: U2.9 (PD0), U7.15 (P0)
unnamed: U2.10 (PD1), U7.14 (P1)
unnamed: U2.11 (PD2), U3.6 (Oa=b)
unnamed: U3.10 (A0), U4.15 (Q5)
unnamed: U3.12 (A1), U4.12 (Q4)
unnamed: U3.13 (A2), U4.10 (Q3)
unnamed: U3.15 (A3), U4.7 (Q2)
unnamed: U4.3 (D0), U6.7 (Q2)
unnamed: U4.4 (D1), U6.10 (Q3)
unnamed: U4.5 (Q1), U4.6 (D2)
unnamed: U4.2 (Q0), U4.11 (D3)
unnamed: U4.13 (D4), U6.12 (Q4)
unnamed: U4.14 (D5), U6.15 (Q5)
unnamed: U6.5 (Q1), U6.13 (D4)
unnamed: U6.2 (Q0), U6.14 (D5)
R1: U7.2 (Q1); also elsewhere on the board
R2: U7.3 (Q2); also elsewhere on the board
R3: U7.4 (Q3); also elsewhere on the board
R4: U7.5 (Q4); also elsewhere on the board
R5: U7.6 (Q5); also elsewhere on the board
R6: U7.7 (Q6); also elsewhere on the board
R7: U7.9 (Q7); also elsewhere on the board
R8: U7.10 (Q8); also elsewhere on the board
R9: U7.11 (Q9); also elsewhere on the board
R10: U7.1 (Q0); also elsewhere on the board
S0: U2.37 (PA0), U3.9 (B0), U6.3 (D0); also elsewhere on the board
S1: U2.36 (PA1), U3.11 (B1), U6.4 (D1); also elsewhere on the board
S2: U2.35 (PA2), U3.14 (B2), U6.6 (D2); also elsewhere on the board
S3: U2.34 (PA3), U3.1 (B3), U6.11 (D3); also elsewhere on the board
SCL: U2.19 (PC0); also elsewhere on the board
SDA: U2.20 (PC1); also elsewhere on the board
VCC: C8.1, C9.1, C10.1, C11.1, C12.1, C30.2, J4.2 (VCC), U2.5 (VCC), U2.17 (VCC), U2.27 (AVCC), U2.29 (AREF), U2.38 (VCC), U3.3 (Ia=b), U3.16 (VCC), U4.1 (~Mr), U4.16 (VCC), U6.1 (~Mr), U6.16 (VCC), U7.16 (VCC); also elsewhere on the board
VCC33: C7.1, Y1.1 (EN), Y1.4 (Vdd); also elsewhere on the board
cR1: D1.2 (A); also elsewhere on the board

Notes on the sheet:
CBM-KEYB-PETN-3.0B-20251102
This AtMega translates keyboard maps - S0-S1 inputs are on port bits PA0-3, on a port not written to. Reason is they can be read and converted into a table index using ANDI #15 - PA4/5 could in theory be used to extend the keyboard mapping table - PD2 is falling edge triggered interrupt, fed from t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
(C) 2020,2021 Steve J. Gray (C) 2025 André Fachat

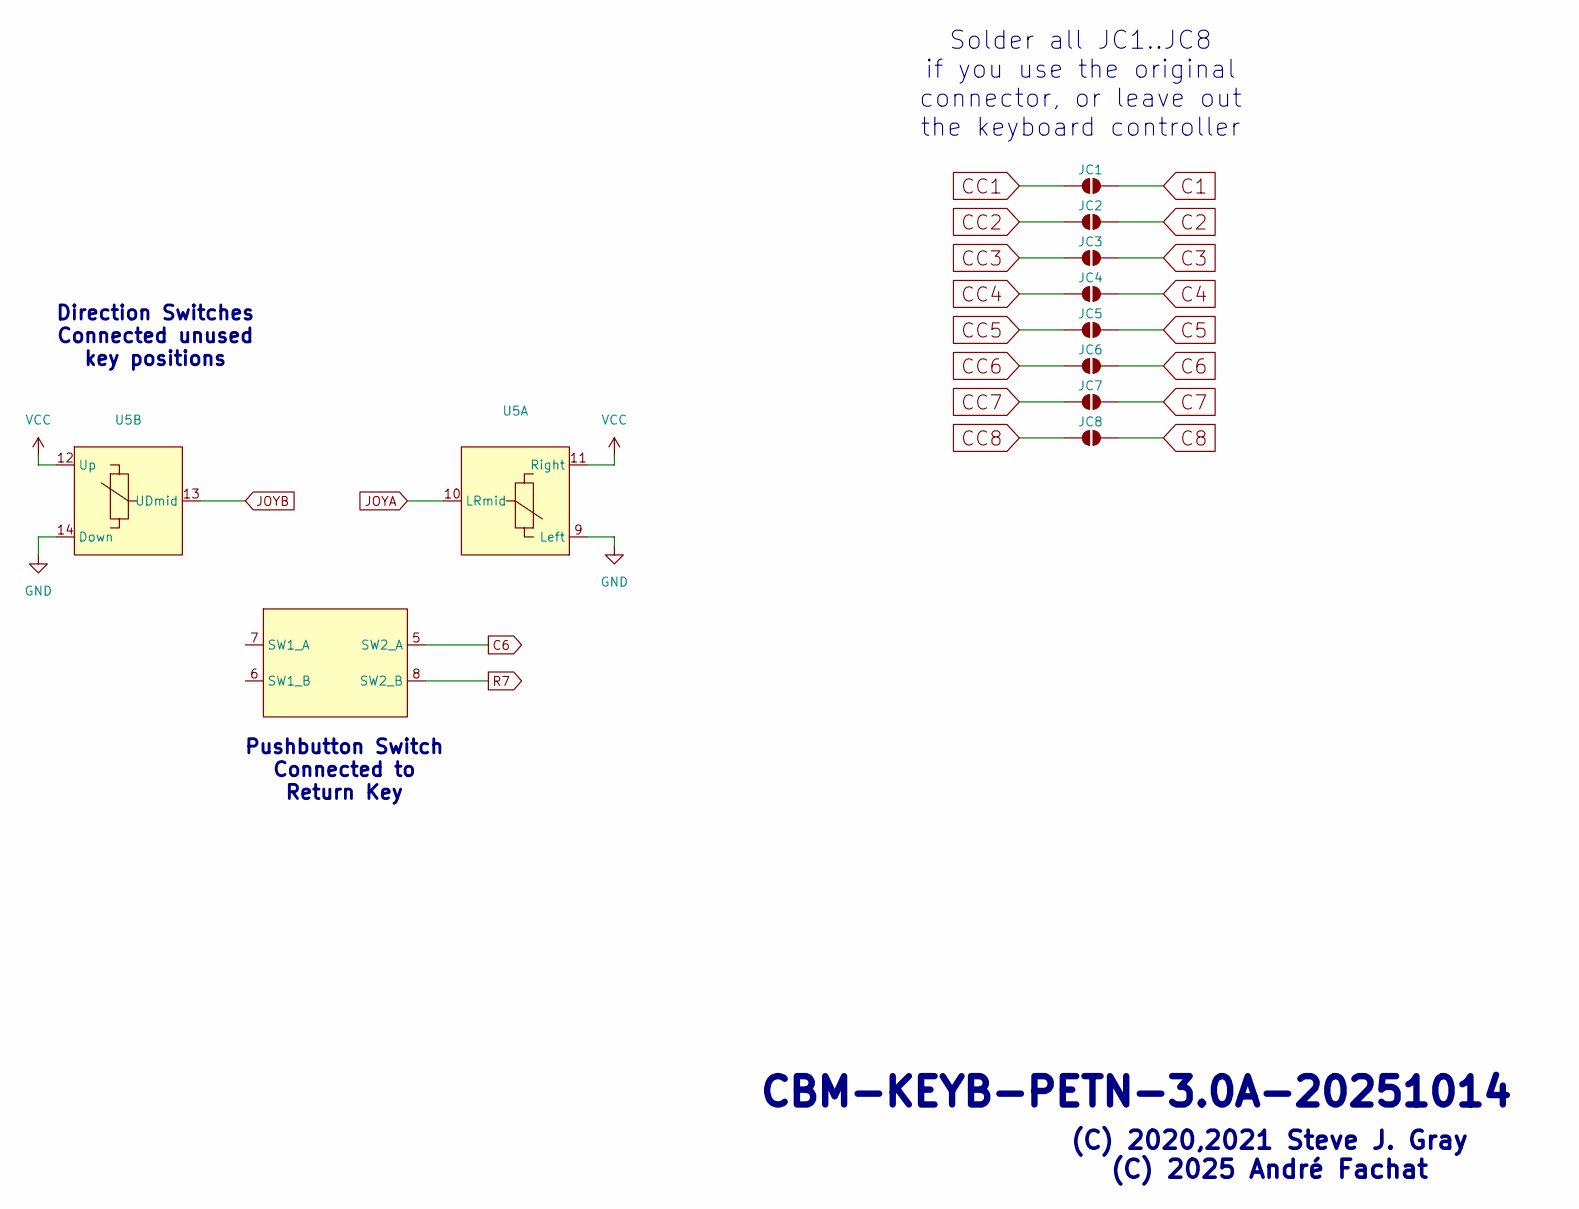
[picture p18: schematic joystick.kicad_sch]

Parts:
JC1, JC2, JC3, JC4, JC5, JC6, JC7, JC8: SolderJumper_2_Bridged; SolderJumper-2_P1.3mm_Open_RoundedPad1.0x1.5mm
U5: THB Miniature Thumbstick THB001P; Mouser 611-THB001P

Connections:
C1: JC1.2 (B); also elsewhere on the board
C2: JC2.2 (B); also elsewhere on the board
C3: JC3.2 (B); also elsewhere on the board
C4: JC4.2 (B); also elsewhere on the board
C5: JC5.2 (B); also elsewhere on the board
C6: JC6.2 (B), U5.5 (SW2_A); also elsewhere on the board
C7: JC7.2 (B); also elsewhere on the board
C8: JC8.2 (B); also elsewhere on the board
CC1: JC1.1 (A); also elsewhere on the board
CC2: JC2.1 (A); also elsewhere on the board
CC3: JC3.1 (A); also elsewhere on the board
CC4: JC4.1 (A); also elsewhere on the board
CC5: JC5.1 (A); also elsewhere on the board
CC6: JC6.1 (A); also elsewhere on the board
CC7: JC7.1 (A); also elsewhere on the board
CC8: JC8.1 (A); also elsewhere on the board
GND: U5.9 (Left), U5.14 (Down); also elsewhere on the board
JOYA: U5.10 (LRmid); also elsewhere on the board
JOYB: U5.13 (UDmid); also elsewhere on the board
R7: U5.8 (SW2_B); also elsewhere on the board
VCC: U5.11 (Right), U5.12 (Up); also elsewhere on the board

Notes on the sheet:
CBM-KEYB-PETN-3.0A-20251014
Pushbutton Switch Connected to Return Key
(C) 2020,2021 Steve J. Gray (C) 2025 André Fachat
Solder all JC1..JC8 if you use the original connector, or leave out the keyboard controller
Direction Switches Connected unused key positions

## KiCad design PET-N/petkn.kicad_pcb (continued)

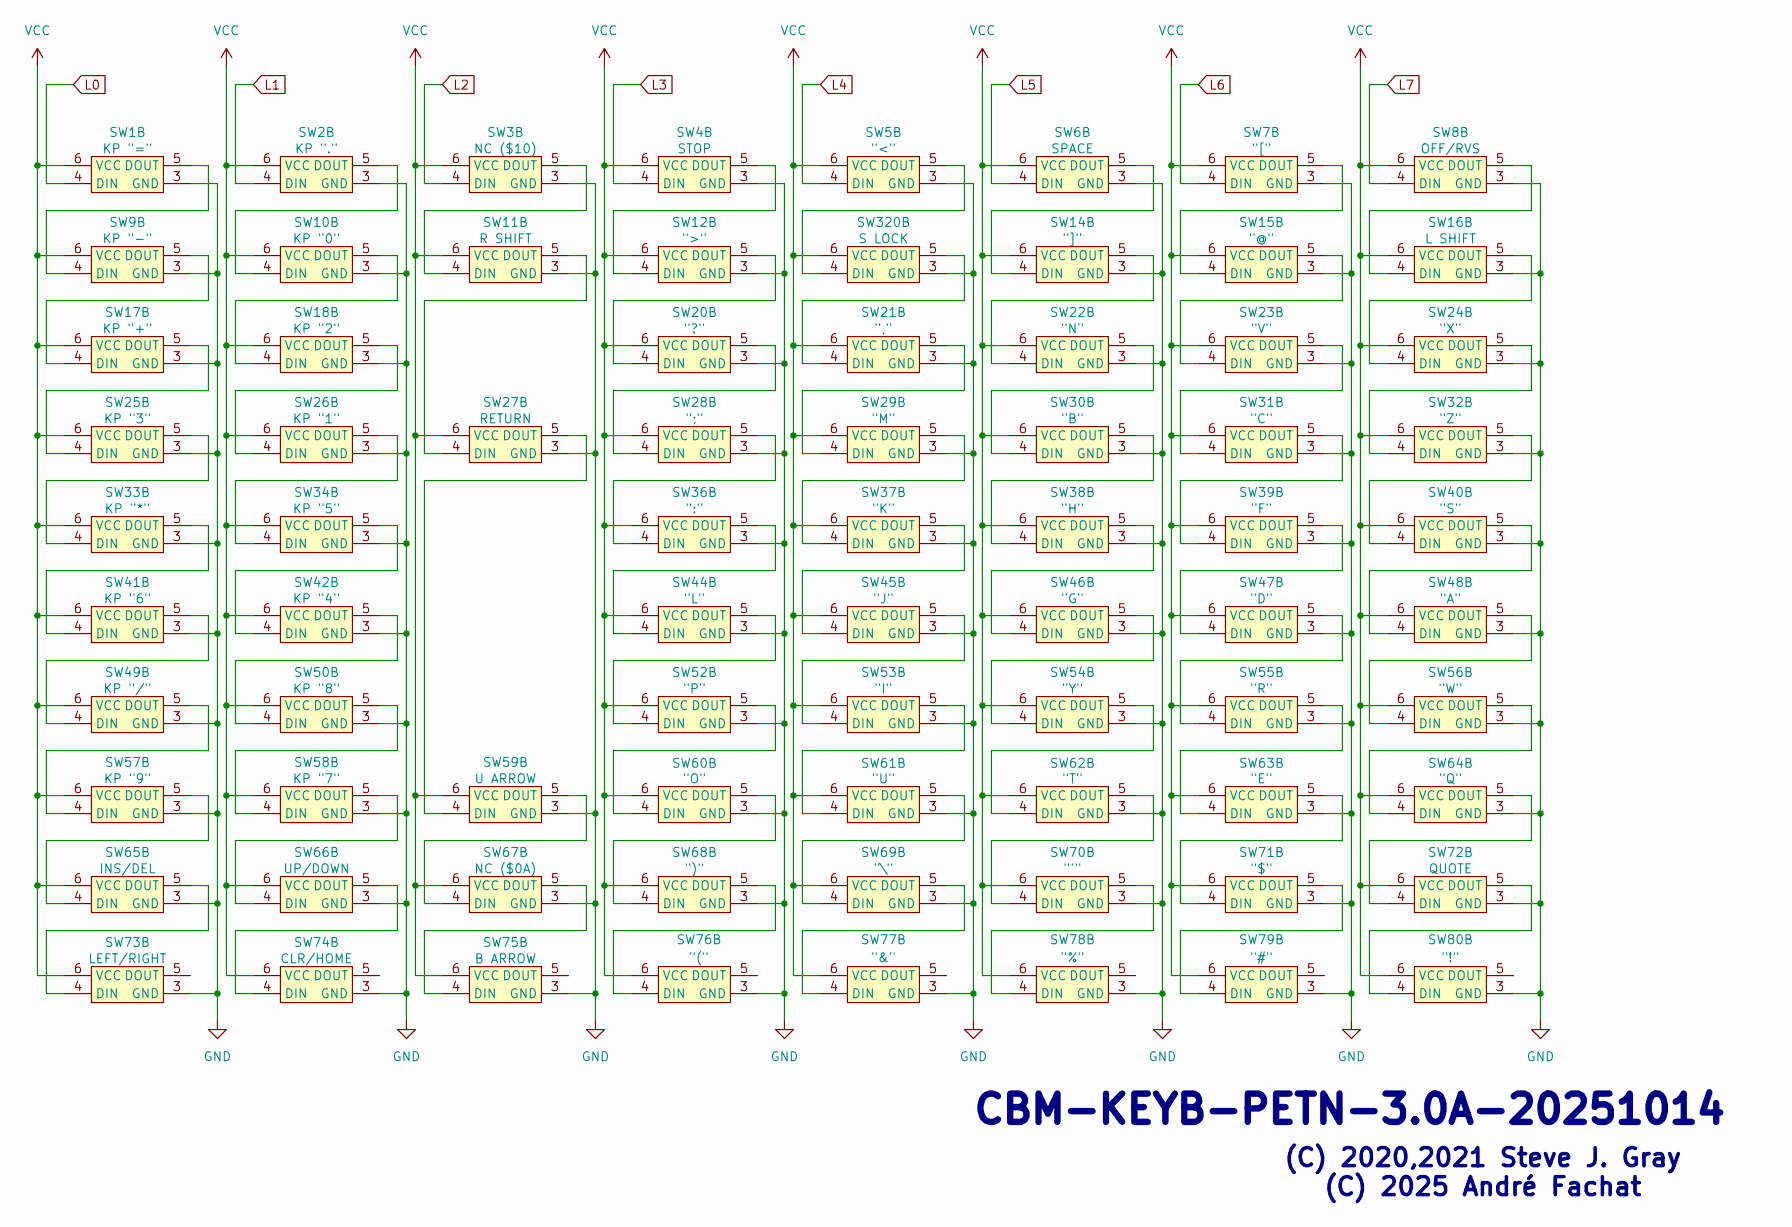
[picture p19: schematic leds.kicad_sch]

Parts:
SW1: KP "="; SW_Cherry_MX_1.00u_PCB_with_RGB_LED
SW2: KP "."; SW_Cherry_MX_1.00u_PCB_with_RGB_LED
SW3: NC ($10); SW_Cherry_MX_1.25u_PCB_with_RGB_LED
SW4: STOP; SW_Cherry_MX_1.00u_PCB_with_RGB_LED
SW5: "<"; SW_Cherry_MX_1.00u_PCB_with_RGB_LED
SW6: SPACE; SW_Cherry_MX_6.25u_PCB_with_RGB_LED
SW7: "["; SW_Cherry_MX_1.00u_PCB_with_RGB_LED
SW8: OFF/RVS; SW_Cherry_MX_1.50u_PCB_with_RGB_LED
SW9: KP "-"; SW_Cherry_MX_1.00u_PCB_with_RGB_LED
SW10: KP "0"; SW_Cherry_MX_1.00u_PCB_with_RGB_LED
SW11: R SHIFT; SW_Cherry_MX_2.00u_PCB_with_RGB_LED
SW12: ">"; SW_Cherry_MX_1.00u_PCB_with_RGB_LED
SW14: "]"; SW_Cherry_MX_1.00u_PCB_with_RGB_LED
SW15: "@"; SW_Cherry_MX_1.00u_PCB_with_RGB_LED
SW16: L SHIFT; SW_Cherry_MX_2.00u_PCB_with_RGB_LED
SW17: KP "+"; SW_Cherry_MX_1.00u_PCB_with_RGB_LED
SW18: KP "2"; SW_Cherry_MX_1.00u_PCB_with_RGB_LED
SW20: "?"; SW_Cherry_MX_1.00u_PCB_with_RGB_LED
SW21: ","; SW_Cherry_MX_1.00u_PCB_with_RGB_LED
SW22: "N"; SW_Cherry_MX_1.00u_PCB_with_RGB_LED
SW23: "V"; SW_Cherry_MX_1.00u_PCB_with_RGB_LED
SW24: "X"; SW_Cherry_MX_1.00u_PCB_with_RGB_LED
SW25: KP "3"; SW_Cherry_MX_1.00u_PCB_with_RGB_LED
SW26: KP "1"; SW_Cherry_MX_1.00u_PCB_with_RGB_LED
SW27: RETURN; SW_Cherry_MX_1.50u_PCB_with_RGB_LED
SW28: ";"; SW_Cherry_MX_1.00u_PCB_with_RGB_LED
SW29: "M"; SW_Cherry_MX_1.00u_PCB_with_RGB_LED
SW30: "B"; SW_Cherry_MX_1.00u_PCB_with_RGB_LED
SW31: "C"; SW_Cherry_MX_1.00u_PCB_with_RGB_LED
SW32: "Z"; SW_Cherry_MX_1.00u_PCB_with_RGB_LED
SW33: KP "*"; SW_Cherry_MX_1.00u_PCB_with_RGB_LED
SW34: KP "5"; SW_Cherry_MX_1.00u_PCB_with_RGB_LED
SW36: ":"; SW_Cherry_MX_1.00u_PCB_with_RGB_LED
SW37: "K"; SW_Cherry_MX_1.00u_PCB_with_RGB_LED
SW38: "H"; SW_Cherry_MX_1.00u_PCB_with_RGB_LED
SW39: "F"; SW_Cherry_MX_1.00u_PCB_with_RGB_LED
SW40: "S"; SW_Cherry_MX_1.00u_PCB_with_RGB_LED
SW41: KP "6"; SW_Cherry_MX_1.00u_PCB_with_RGB_LED
SW42: KP "4"; SW_Cherry_MX_1.00u_PCB_with_RGB_LED
SW44: "L"; SW_Cherry_MX_1.00u_PCB_with_RGB_LED
SW45: "J"; SW_Cherry_MX_1.00u_PCB_with_RGB_LED
SW46: "G"; SW_Cherry_MX_1.00u_PCB_with_RGB_LED
SW47: "D"; SW_Cherry_MX_1.00u_PCB_with_RGB_LED
SW48: "A"; SW_Cherry_MX_1.00u_PCB_with_RGB_LED
SW49: KP "/"; SW_Cherry_MX_1.00u_PCB_with_RGB_LED
SW50: KP "8"; SW_Cherry_MX_1.00u_PCB_with_RGB_LED
SW52: "P"; SW_Cherry_MX_1.00u_PCB_with_RGB_LED
SW53: "I"; SW_Cherry_MX_1.00u_PCB_with_RGB_LED
SW54: "Y"; SW_Cherry_MX_1.00u_PCB_with_RGB_LED
SW55: "R"; SW_Cherry_MX_1.00u_PCB_with_RGB_LED
SW56: "W"; SW_Cherry_MX_1.00u_PCB_with_RGB_LED
SW57: KP "9"; SW_Cherry_MX_1.00u_PCB_with_RGB_LED
SW58: KP "7"; SW_Cherry_MX_1.00u_PCB_with_RGB_LED
SW59: U ARROW; SW_Cherry_MX_1.00u_PCB_with_RGB_LED
SW60: "O"; SW_Cherry_MX_1.00u_PCB_with_RGB_LED
SW61: "U"; SW_Cherry_MX_1.00u_PCB_with_RGB_LED
SW62: "T"; SW_Cherry_MX_1.00u_PCB_with_RGB_LED
SW63: "E"; SW_Cherry_MX_1.00u_PCB_with_RGB_LED
SW64: "Q"; SW_Cherry_MX_1.00u_PCB_with_RGB_LED
SW65: INS/DEL; SW_Cherry_MX_1.00u_PCB_with_RGB_LED
SW66: UP/DOWN; SW_Cherry_MX_1.00u_PCB_with_RGB_LED
SW67: NC ($0A); SW_Cherry_MX_1.50u_PCB_with_RGB_LED
SW68: ")"; SW_Cherry_MX_1.00u_PCB_with_RGB_LED
SW69: "\"; SW_Cherry_MX_1.00u_PCB_with_RGB_LED
SW70: "'"; SW_Cherry_MX_1.00u_PCB_with_RGB_LED
SW71: "$"; SW_Cherry_MX_1.00u_PCB_with_RGB_LED
SW72: QUOTE; SW_Cherry_MX_1.00u_PCB_with_RGB_LED
SW73: LEFT/RIGHT; SW_Cherry_MX_1.00u_PCB_with_RGB_LED
SW74: CLR/HOME; SW_Cherry_MX_1.00u_PCB_with_RGB_LED
SW75: B ARROW; SW_Cherry_MX_1.00u_PCB_with_RGB_LED
SW76: "("; SW_Cherry_MX_1.00u_PCB_with_RGB_LED
SW77: "&"; SW_Cherry_MX_1.00u_PCB_with_RGB_LED
SW78: "%"; SW_Cherry_MX_1.00u_PCB_with_RGB_LED
SW79: "#"; SW_Cherry_MX_1.00u_PCB_with_RGB_LED
SW80: "!"; SW_Cherry_MX_1.00u_PCB_with_RGB_LED
SW320: S LOCK; SW_Cherry_MX_1.50u_PCB_with_RGB_LED

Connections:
GND: SW1.3 (GND), SW2.3 (GND), SW3.3 (GND), SW4.3 (GND), SW5.3 (GND), SW6.3 (GND), SW7.3 (GND), SW8.3 (GND), SW9.3 (GND), SW10.3 (GND), SW11.3 (GND), SW12.3 (GND), SW14.3 (GND), SW15.3 (GND), SW16.3 (GND), SW17.3 (GND), SW18.3 (GND), SW20.3 (GND), SW21.3 (GND), SW22.3 (GND), SW23.3 (GND), SW24.3 (GND), SW25.3 (GND), SW26.3 (GND), SW27.3 (GND), SW28.3 (GND), SW29.3 (GND), SW30.3 (GND), SW31.3 (GND), SW32.3 (GND), SW33.3 (GND), SW34.3 (GND), SW36.3 (GND), SW37.3 (GND), SW38.3 (GND), SW39.3 (GND), SW40.3 (GND), SW41.3 (GND), SW42.3 (GND), SW44.3 (GND), SW45.3 (GND), SW46.3 (GND), SW47.3 (GND), SW48.3 (GND), SW49.3 (GND), SW50.3 (GND), SW52.3 (GND), SW53.3 (GND), SW54.3 (GND), SW55.3 (GND), SW56.3 (GND), SW57.3 (GND), SW58.3 (GND), SW59.3 (GND), SW60.3 (GND), SW61.3 (GND), SW62.3 (GND), SW63.3 (GND), SW64.3 (GND), SW65.3 (GND), SW66.3 (GND), SW67.3 (GND), SW68.3 (GND), SW69.3 (GND), SW70.3 (GND), SW71.3 (GND), SW72.3 (GND), SW73.3 (GND), SW74.3 (GND), SW75.3 (GND), SW76.3 (GND), SW77.3 (GND), SW78.3 (GND), SW79.3 (GND), SW80.3 (GND), SW320.3 (GND); also elsewhere on the board
L0: SW1.4 (DIN); also elsewhere on the board
L1: SW2.4 (DIN); also elsewhere on the board
L2: SW3.4 (DIN); also elsewhere on the board
L3: SW4.4 (DIN); also elsewhere on the board
L4: SW5.4 (DIN); also elsewhere on the board
L5: SW6.4 (DIN); also elsewhere on the board
L6: SW7.4 (DIN); also elsewhere on the board
L7: SW8.4 (DIN); also elsewhere on the board
unnamed: SW1.5 (DOUT), SW9.4 (DIN)
unnamed: SW2.5 (DOUT), SW10.4 (DIN)
unnamed: SW10.5 (DOUT), SW18.4 (DIN)
unnamed: SW3.5 (DOUT), SW11.4 (DIN)
unnamed: SW11.5 (DOUT), SW27.4 (DIN)
unnamed: SW4.5 (DOUT), SW12.4 (DIN)
unnamed: SW12.5 (DOUT), SW20.4 (DIN)
unnamed: SW6.5 (DOUT), SW14.4 (DIN)
unnamed: SW14.5 (DOUT), SW22.4 (DIN)
unnamed: SW7.5 (DOUT), SW15.4 (DIN)
unnamed: SW15.5 (DOUT), SW23.4 (DIN)
unnamed: SW8.5 (DOUT), SW16.4 (DIN)
unnamed: SW16.5 (DOUT), SW24.4 (DIN)
unnamed: SW9.5 (DOUT), SW17.4 (DIN)
unnamed: SW17.5 (DOUT), SW25.4 (DIN)
unnamed: SW18.5 (DOUT), SW26.4 (DIN)
unnamed: SW20.5 (DOUT), SW28.4 (DIN)
unnamed: SW21.4 (DIN), SW320.5 (DOUT)
unnamed: SW21.5 (DOUT), SW29.4 (DIN)
unnamed: SW22.5 (DOUT), SW30.4 (DIN)
unnamed: SW23.5 (DOUT), SW31.4 (DIN)
unnamed: SW24.5 (DOUT), SW32.4 (DIN)
unnamed: SW25.5 (DOUT), SW33.4 (DIN)
unnamed: SW26.5 (DOUT), SW34.4 (DIN)
unnamed: SW27.5 (DOUT), SW59.4 (DIN)
unnamed: SW28.5 (DOUT), SW36.4 (DIN)
unnamed: SW29.5 (DOUT), SW37.4 (DIN)
unnamed: SW30.5 (DOUT), SW38.4 (DIN)
unnamed: SW31.5 (DOUT), SW39.4 (DIN)
unnamed: SW32.5 (DOUT), SW40.4 (DIN)
unnamed: SW33.5 (DOUT), SW41.4 (DIN)
unnamed: SW34.5 (DOUT), SW42.4 (DIN)
unnamed: SW36.5 (DOUT), SW44.4 (DIN)
unnamed: SW37.5 (DOUT), SW45.4 (DIN)
unnamed: SW38.5 (DOUT), SW46.4 (DIN)
unnamed: SW39.5 (DOUT), SW47.4 (DIN)
unnamed: SW40.5 (DOUT), SW48.4 (DIN)
unnamed: SW41.5 (DOUT), SW49.4 (DIN)
unnamed: SW42.5 (DOUT), SW50.4 (DIN)
unnamed: SW44.5 (DOUT), SW52.4 (DIN)
unnamed: SW45.5 (DOUT), SW53.4 (DIN)
unnamed: SW46.5 (DOUT), SW54.4 (DIN)
unnamed: SW47.5 (DOUT), SW55.4 (DIN)
unnamed: SW48.5 (DOUT), SW56.4 (DIN)
unnamed: SW49.5 (DOUT), SW57.4 (DIN)
unnamed: SW50.5 (DOUT), SW58.4 (DIN)
unnamed: SW52.5 (DOUT), SW60.4 (DIN)
unnamed: SW53.5 (DOUT), SW61.4 (DIN)
unnamed: SW54.5 (DOUT), SW62.4 (DIN)
unnamed: SW55.5 (DOUT), SW63.4 (DIN)
unnamed: SW56.5 (DOUT), SW64.4 (DIN)
unnamed: SW57.5 (DOUT), SW65.4 (DIN)
unnamed: SW58.5 (DOUT), SW66.4 (DIN)
unnamed: SW59.5 (DOUT), SW67.4 (DIN)
unnamed: SW60.5 (DOUT), SW68.4 (DIN)
unnamed: SW61.5 (DOUT), SW69.4 (DIN)
unnamed: SW62.5 (DOUT), SW70.4 (DIN)
unnamed: SW63.5 (DOUT), SW71.4 (DIN)
unnamed: SW64.5 (DOUT), SW72.4 (DIN)
unnamed: SW65.5 (DOUT), SW73.4 (DIN)
unnamed: SW66.5 (DOUT), SW74.4 (DIN)
unnamed: SW67.5 (DOUT), SW75.4 (DIN)
unnamed: SW68.5 (DOUT), SW76.4 (DIN)
unnamed: SW69.5 (DOUT), SW77.4 (DIN)
unnamed: SW70.5 (DOUT), SW78.4 (DIN)
unnamed: SW71.5 (DOUT), SW79.4 (DIN)
unnamed: SW72.5 (DOUT), SW80.4 (DIN)
unnamed: SW5.5 (DOUT), SW320.4 (DIN)
VCC: SW1.6 (VCC), SW2.6 (VCC), SW3.6 (VCC), SW4.6 (VCC), SW5.6 (VCC), SW6.6 (VCC), SW7.6 (VCC), SW8.6 (VCC), SW9.6 (VCC), SW10.6 (VCC), SW11.6 (VCC), SW12.6 (VCC), SW14.6 (VCC), SW15.6 (VCC), SW16.6 (VCC), SW17.6 (VCC), SW18.6 (VCC), SW20.6 (VCC), SW21.6 (VCC), SW22.6 (VCC), SW23.6 (VCC), SW24.6 (VCC), SW25.6 (VCC), SW26.6 (VCC), SW27.6 (VCC), SW28.6 (VCC), SW29.6 (VCC), SW30.6 (VCC), SW31.6 (VCC), SW32.6 (VCC), SW33.6 (VCC), SW34.6 (VCC), SW36.6 (VCC), SW37.6 (VCC), SW38.6 (VCC), SW39.6 (VCC), SW40.6 (VCC), SW41.6 (VCC), SW42.6 (VCC), SW44.6 (VCC), SW45.6 (VCC), SW46.6 (VCC), SW47.6 (VCC), SW48.6 (VCC), SW49.6 (VCC), SW50.6 (VCC), SW52.6 (VCC), SW53.6 (VCC), SW54.6 (VCC), SW55.6 (VCC), SW56.6 (VCC), SW57.6 (VCC), SW58.6 (VCC), SW59.6 (VCC), SW60.6 (VCC), SW61.6 (VCC), SW62.6 (VCC), SW63.6 (VCC), SW64.6 (VCC), SW65.6 (VCC), SW66.6 (VCC), SW67.6 (VCC), SW68.6 (VCC), SW69.6 (VCC), SW70.6 (VCC), SW71.6 (VCC), SW72.6 (VCC), SW73.6 (VCC), SW74.6 (VCC), SW75.6 (VCC), SW76.6 (VCC), SW77.6 (VCC), SW78.6 (VCC), SW79.6 (VCC), SW80.6 (VCC), SW320.6 (VCC); also elsewhere on the board

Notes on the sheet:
CBM-KEYB-PETN-3.0A-20251014
(C) 2020,2021 Steve J. Gray (C) 2025 André Fachat

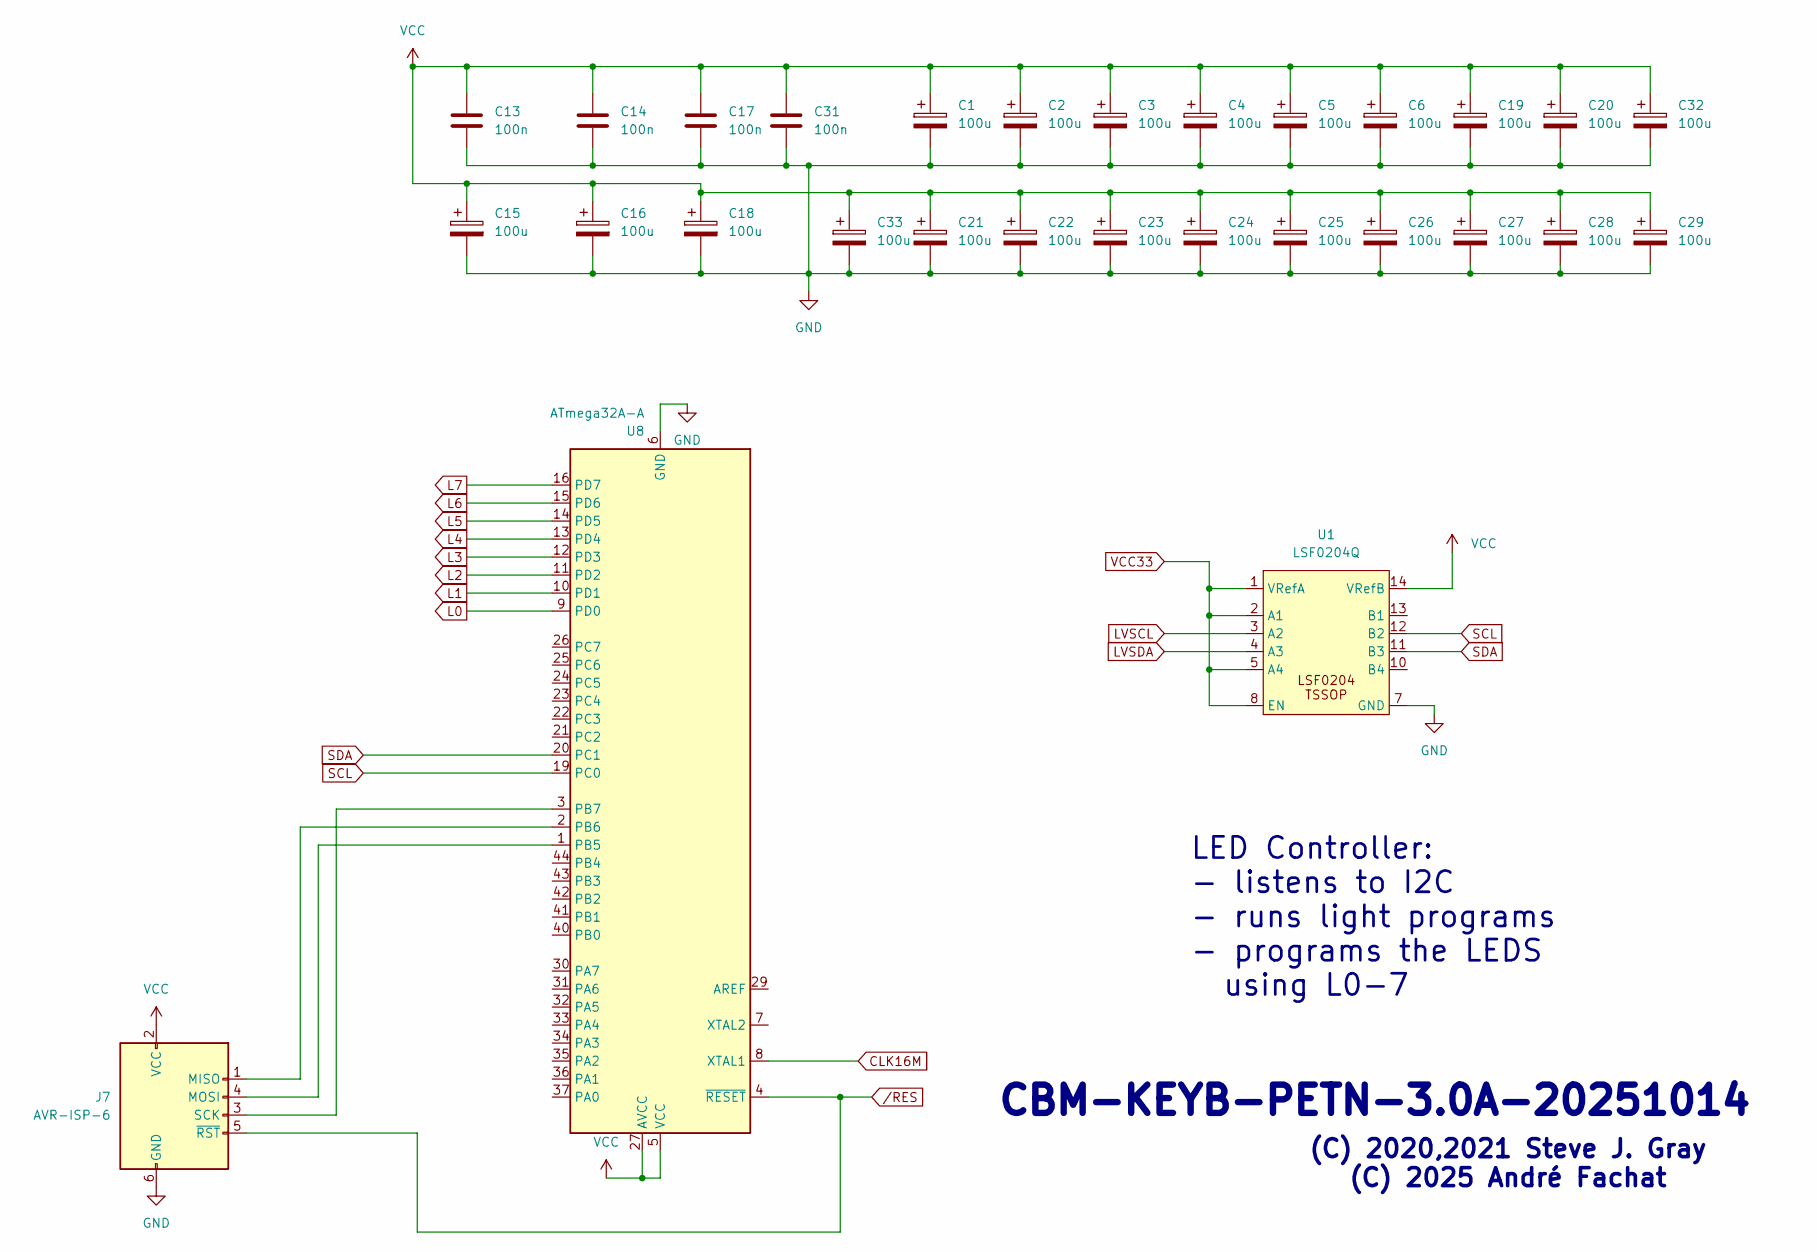
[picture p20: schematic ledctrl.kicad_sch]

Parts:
C1, C2, C3, C4, C5, C6, C15, C16, C18, C19, C20, C21, C22, C23, C24, C25, C26, C27, C28, C29, C32, C33: 100u; C_1206_3216Metric_Pad1.33x1.80mm_HandSolder; LCSC C15008
C13, C14, C17, C31: 100n; C_0805_2012Metric_Pad1.18x1.45mm_HandSolder; LCSC C14663
J7: AVR-ISP-6; IDC-Header_2x03_P2.54mm_Vertical; LCSC C5372863
U1: LSF0204Q; TSSOP-14_4.4x5mm_P0.65mm; LCSC C2677502
U8: ATmega32A-A; TQFP-44_10x10mm_P0.8mm; LCSC C5659

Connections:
CLK16M: U8.8 (XTAL1); also elsewhere on the board
GND: C1.2, C2.2, C3.2, C4.2, C5.2, C6.2, C13.2, C14.2, C15.2, C16.2, C17.2, C18.2, C19.2, C20.2, C21.2, C22.2, C23.2, C24.2, C25.2, C26.2, C27.2, C28.2, C29.2, C31.2, C32.2, C33.2, J7.6 (GND), U1.7 (GND), U8.6 (GND), U8.18 (GND), U8.28 (GND), U8.39 (GND); also elsewhere on the board
L0: U8.9 (PD0); also elsewhere on the board
L1: U8.10 (PD1); also elsewhere on the board
L2: U8.11 (PD2); also elsewhere on the board
L3: U8.12 (PD3); also elsewhere on the board
L4: U8.13 (PD4); also elsewhere on the board
L5: U8.14 (PD5); also elsewhere on the board
L6: U8.15 (PD6); also elsewhere on the board
L7: U8.16 (PD7); also elsewhere on the board
LVSCL: U1.3 (A2); also elsewhere on the board
LVSDA: U1.4 (A3); also elsewhere on the board
unnamed: J7.1 (MISO), U8.2 (PB6)
unnamed: J7.4 (MOSI), U8.1 (PB5)
unnamed: J7.3 (SCK), U8.3 (PB7)
SCL: U1.12 (B2), U8.19 (PC0); also elsewhere on the board
SDA: U1.11 (B3), U8.20 (PC1); also elsewhere on the board
VCC: C1.1, C2.1, C3.1, C4.1, C5.1, C6.1, C13.1, C14.1, C15.1, C16.1, C17.1, C18.1, C19.1, C20.1, C21.1, C22.1, C23.1, C24.1, C25.1, C26.1, C27.1, C28.1, C29.1, C31.1, C32.1, C33.1, J7.2 (VCC), U1.14 (VRefB), U8.5 (VCC), U8.17 (VCC), U8.27 (AVCC), U8.38 (VCC); also elsewhere on the board
VCC33: U1.1 (VRefA), U1.2 (A1), U1.5 (A4), U1.8 (EN); also elsewhere on the board
cR1: J7.5 (~RST), U8.4 (~RESET); also elsewhere on the board

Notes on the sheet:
(C) 2020,2021 Steve J. Gray (C) 2025 André Fachat
LED Controller: - listens to I2C - runs light programs - programs the LEDS using L0-7
CBM-KEYB-PETN-3.0A-20251014

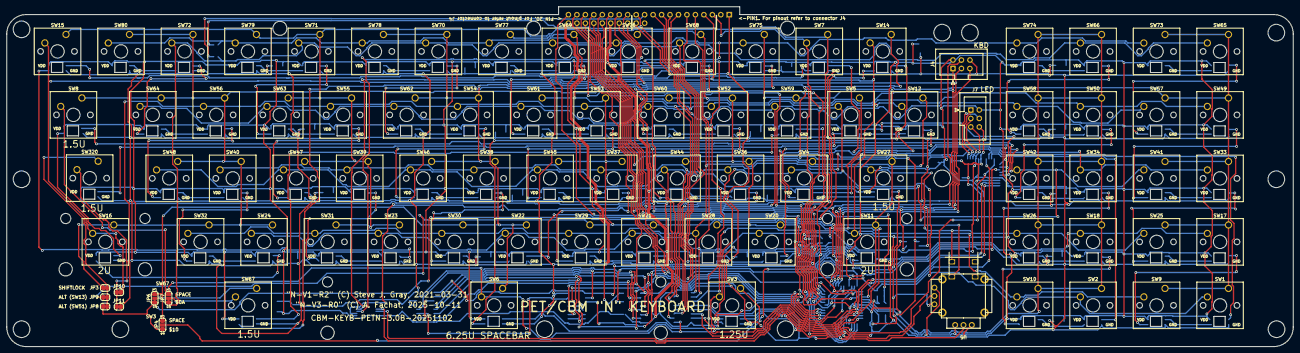
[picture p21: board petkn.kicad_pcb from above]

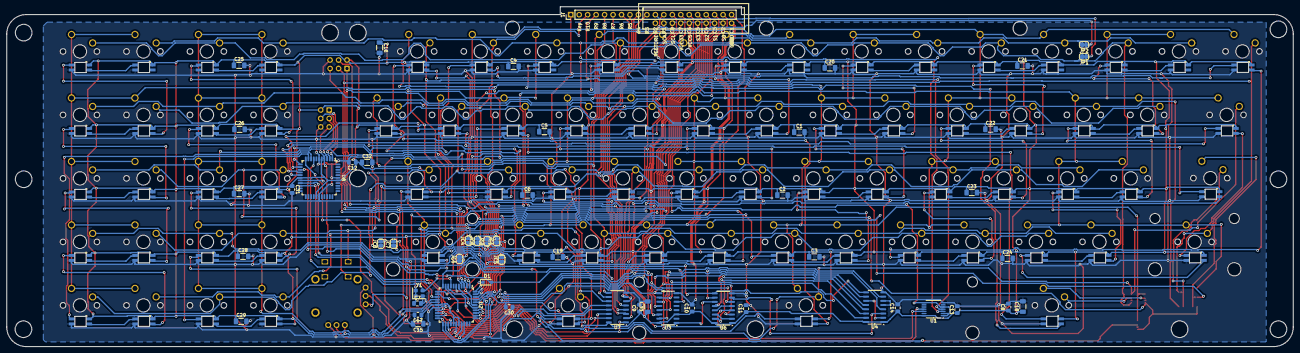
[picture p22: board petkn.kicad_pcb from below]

Board: 2 copper layers, 386.1 x 102.0 mm, 140 parts (53 on the bottom side), 145 nets.

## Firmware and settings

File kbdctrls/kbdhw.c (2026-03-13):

#include <string.h>
#include <util/delay.h>
#include <avr/io.h>
#include <avr/interrupt.h>

#include "kbdhw.h"
#include "map.h"

unsigned char scanvals[16];
static unsigned char rowvals[16];

/*
 * Connection to the actual host
 */
void host_setup() {

	memset(rowvals, 0, 16);

	// disable UART (alt fun conflicts with I/O)
	UCSRB = 0;
	// JTAG needs to be disabled by HFUSE

	// port A0-3 is select lines in from host
	DDRA &= 0xf0;
	// no pullups
	PORTA &= 0xf0;

	// PB 0-7 are "open collector" outputs; 
	// i.e. only set to output 0 when active, otherwise input
	// PB 5-7 are SPI prog lines, doubling as output to Host
	DDRB &= 0x00;
	// no pullups, set to output 0 when active to pull low
	PORTB &= 0x00;

	// PD3 is output to /RES when pulled low
	PORTD |= 0x08;
	DDRD |= 0x08;

	// interrupt handling
	// PD2 and PD3 are interrupt sources, PD2 is INT0 
	// and used as host select change int
	DDRD &= 0xfb;
	// no pullups
	PORTD &= 0xfb;

	// configure int0 on falling edge
	MCUCR = (MCUCR & 0xfc) | 0x02;
	// enable int0
	GICR |= 0x40;

	// own keyboard scan

	// row select bits 0/1 PD0/1
	DDRD |= 0x03;
	PORTD &= 0xfc;
	// row select bits 2/3 PC2/3
	DDRC |= 0x0c;
	PORTC &= 0xf3;

	// column value inputs
	// split on two ports due to needed alt functions for PC0/1, PD2

	// bits 0-3 are PC4-7, input with pullup
	DDRC &= 0x0f;
	PORTC |= 0xf0;
	// bits 4-7 are PD4-7, input with pullup
	DDRD &= 0x0f;
	PORTD |= 0xf0;

	// set PA0 to analog input,

	// AREF = AVCC
	// left adjust so we only need to use the
	// high byte with 8 bit resolution
	// select A7
	ADMUX = 0x67;
	// enable ADC
	ADCSRA = 0x80;

	sei();
}

/*
 * note this ISR sets DDRA in less than 2.3us
 * which is very much enough for a 1-4 MHz PET scan routine
 * but not for a 13.5 MHz speed machine. 
 *
 * The normal scan reads the byte, then compares it again.
 * The first read happens on cycle 8 after change, the second on cycle 11.
 * See $e4be and following in the BASIC 4
 *
 * So, we have 11 cycles at 13.5 MHz, or 810ns only to write the correct
 * value ...
 *
 */
ISR( INT0_vect ) {
	DDRB = rowvals[PINA & 0x0f];
	//PORTD ^= 0x01;
}

/*
 * set the RES line active to reset the host
 */
void set_reset(int reset) {
	if (reset) {
		// res low
		PORTD &= 0xf7;
	} else {
		PORTD |= 0x08;
	}
}

/*
 * scan the joystick
 */
void joy_scan() {
	unsigned char val;

	// prescaler 7 = 1/128 = 125kHz
	ADCSRA = 0x07;

	//ADCSRA |= 1 << ADEN;

	// --------------------------------------------
	// measure up/down

	ADMUX = 0x67;


	// disable interrupt flag
	ADCSRA |= 1 << ADIF;

	// enable conversion
	ADCSRA |= 1 << ADEN;

	//start conversion
	ADCSRA |= 1 << ADSC;

	while (ADCSRA & (1<<ADSC)) { }

		// ADSC done
	
		// we use left adjust, so only high byte needed	
		val = ADCH;

		// max value is 0xff
		// mid value is 0x80
		// low water we define as 0x40
		// high water we set to 0xc0
		if (val < 0x40) {
			// set crsr up
			scanvals[1] |= 0x40;
			scanvals[8] |= 0x20;
		} else
		if (val > 0xc0) {
			// set crsr down
			scanvals[1] |= 0x40;
		}
//	}
	
	// --------------------------------------------
	// measure left/right

	ADCSRA = 0x07;

	ADMUX = 0x66;

	// disable interrupt flag
	ADCSRA |= 1 << ADIF;

	ADCSRA |= 1 << ADEN;

	//start conversion
	ADCSRA |= 1 << ADSC;

	while (ADCSRA & (1<<ADSC)) { }
		// ADIF set
	
		// we use left adjust, so only high byte needed	
		val = ADCH;

		// max value is 0xff
		// mid value is 0x80
		// low water we define as 0x40
		// high water we set to 0xc0
		if (val < 0x40) {
			// set crsr right
			scanvals[0] |= 0x80;
		} else
		if (val > 0xc0) {
			// set crsr left
			scanvals[0] |= 0x80;
			scanvals[8] |= 0x20;
		}
	//}	
}

void key_swap() {

	memcpy(rowvals, scanvals, sizeof(rowvals));
}

void scan_clear() {

	memset(scanvals, 0, sizeof(rowvals));
}

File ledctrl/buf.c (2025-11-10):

#include <string.h>
#include <util/delay.h>
#include <avr/io.h>
#include <avr/interrupt.h>

#include "defs.h"
#include "buf.h"


// 8 chains of LEDs, 8 bits per color
// Number of bytes is LEDSPERCHAIN * 3 colors * 8 bits 
#define	BUFLEN		(LEDSPERCHAIN * COLS * 8)

// prepared output bit chain, 1 bit per chain in every byte
unsigned char buf[BUFLEN];

// LED colours, one byte per color (r/g/b), one colorset per key
extern unsigned char rgb[MAXLED][COLSANDPARS];


/*
 * this probably at some point goes into machine language
 *
 * implements the LED control protocol of the SK6812MINI-E 
 * controllable RGB LED:
 *
 * Signal line is a single data line that is passed from 
 * controller to first LED, then from there to the second
 * LED and so on.
 * 
 * Signal reset condition is >80us of low.
 *
 * The protocol transmits 24 bits per LED, with the first
 * 24 bits for the first LED in the chain, the second 24 bits
 * for the 2nd LED and so on.
 * 
 * Each bit is a period of the data line going high, with
 * the value being determined by the duration of the
 * high period:
 *
 * value   min   std   max
 *   0     0.2   0.32  0.4
 *   1     0.58  0.64  1.0
 *
 * The approach chosen here is that we have 8 LED chains
 * of 10 LEDs max each, so that we can set the signal levels
 * for all chains with a single IO byte store.
 * 
 * Timing is selected (planned) as 
 *
 * T=0		: set all I/O bits high
 * T=0.35	: set the I/O bits to the value of the data
 * T=0.7	: set all I/O bits low
 * T=1.4	: end of cycle
 */


void buf_send() {
	int i = 0;

	cli();

	PORTD = 0;

	__builtin_avr_delay_cycles(80*16);

	do {
		PORTD = 255;
		__builtin_avr_delay_cycles(2);
		//_delay_loop_1(1);
		//_delay_ms(1);
		PORTD = buf[i];
		__builtin_avr_delay_cycles(5);
		//_delay_loop_1(1);
		//_delay_ms(1);
		PORTD = 0;
		__builtin_avr_delay_cycles(10);
		i++;
	} while (i < BUFLEN);


	sei();
}


/* 
 * transfer the color per led into the bitstream buffer to prep for
 * transmission to the LED.
 *
 * Note that the storage is R/G/B, but the order of transmission
 * is G/R/B. Also MSB first transmission.
 */
void buf_from_rgb() {

	// shift buffer for current color, one per chain
	char sr[CHAINS];
	//memset(sr, 0, CHAINS * sizeof(char));

	// pointer into buf
	int p = 0;

	// LEDs per chain
	for (int led = 0; led < LEDSPERCHAIN; led++) {

		// all colors
		for (int col = 0; col < COLS; col++) {

			// all chains
			for (int chain = 0; chain < CHAINS; chain++) {

				int k = (LEDSPERCHAIN - led) * CHAINS - chain - 1;
				if (chain == 2) {
					if (led > 1) {
						k -= CHAINS;
					}
					if (led > 2) {
						k -= 3*CHAINS;
					}
				}

				// gather color values per chain
				switch(col) {
				case 0:
					sr[chain] = rgb[k][1];
					break;
				case 1:
					sr[chain] = rgb[k][0];
					break;
				case 2:
					sr[chain] = rgb[k][2];
					break;
				}
			}

			// 8 bits in a color value		
			for (int bit = 0; bit < 8; bit++) {

				unsigned char tmp = 0;
				// 8 chains
				for (int chain = 0; chain < CHAINS; chain++) {
					tmp = tmp >> 1 | (sr[chain] & 128);
					sr[chain] <<= 1;
				}
				buf[p++] = tmp;
			}
		}
	}
}

void buf_setup() {

	UCSRB = 0;
	PORTD = 255;
	DDRD = 255;	// all ports out

	memset(buf, 0, BUFLEN);
}

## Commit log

2025-01-15 added keycap files, images
    [Commodore PET caps for N keyboard fine slices(1).stl, Commodore PET caps for N keyboard fine slices(2).stl, Commodore PET caps for N keyboard fine slices(3).st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]
2025-03-13 add STLs for keyboard support
    [PET-Keyboard-Support-SJG-N-v07-left.stl, PET-Keyboard-Support-SJG-N-v07-right.stl]
2025-05-26 added Steve's PET-N keyboard, converted to kicad 9 (untested)
    [petkn.kicad_pcb, petkn.kicad_sch, petkn.sch]
2025-05-31 first work on adding LEDs and extended connector
    [petkn.kicad_pcb, petkn.kicad_sch]
2025-06-01 add extension page, add 4-to-10 decoder
    [extensions.kicad_sch, petkn.kicad_pcb, petkn.kicad_sch]
2025-06-01 add joystick footprints
    [extensions.kicad_sch]
2025-06-15 test board for LED drivers
    [BOM-test.csv, joysticks.kicad_sch, petkn.kicad_pcb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]
2025-08-11 work on R3 of keyboard pcb
    [decoder.kicad_sch, driver.kicad_sch, extensions.kicad_sch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]
2025-08-12 initial placement
    [extensions.kicad_sch, petkn.kicad_pcb]
2025-08-12 PET-N r3
    [BOM-petkn.csv, decoder.kicad_sch, driver.kicad_sch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]
2025-08-22 work on 2nd update test
    [joysticks.kicad_sch, philips.kicad_sch, test.kicad_pcb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]
2025-08-23 production test pcb
    [BOM-test.csv, philips.kicad_sch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]
2025-08-23 add LSCS parts numbers
    [test.kicad_pcb]
2025-08-24 prod files as submitted
    [CPL-test-fixed.csv, test-CuBottom.gbr, test-CuTop.gbr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]
2025-09-06 add test prog for LED control on V3
2025-09-06 allow sending key programs to the atmega via I2C
2025-09-07 update initial led test pattern
2025-09-17 new schematics version mainly complete
    [keys.kicad_sch, ledctrl.kicad_sch, leds.kicad_sch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]
2025-09-17 remove old schem
    [decoder.kicad_sch, driver.kicad_sch, extensions.kicad_sch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]
2025-09-18 first layout
    [petkn.kicad_pcb]
2025-09-22 layout work
    [petkn.kicad_pcb]
2025-09-28 petn layout work
    [petkn.kicad_pcb]
2025-09-30 more layout work
    [ledctrl.kicad_sch, petkn.kicad_pcb, petkn.kicad_sch]
2025-10-01 add missing pcb trace
    [petkn.kicad_pcb]
2025-10-05 almost done routing; last checks still open
    [joystick.kicad_sch, keys.kicad_sch, ledctrl.kicad_sch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]
2025-10-06 fix Cn vs CCn bug, add proper joystick in schem; routing still to fix
    [joystick.kicad_sch, keys.kicad_sch, petkn.kicad_pcb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]
2025-10-11 hopefully final schem and layout for 3.0A
    [joystick.kicad_sch, keys.kicad_sch, ledctrl.kicad_sch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]
2025-10-11 allow resetting the machine via the IDC connector's /RES line
2025-10-12 small layout updates, jlcpcb production files
    [BOM-petkn.csv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]
2025-10-14 as sent to production
    [BOM-petkn.csv, joystick.kicad_sch, keys.kicad_sch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]
2025-11-01 LED and keyboard controller for the new pet-n-3.0a
2025-11-02 finishing R3.0
    [PET-Keyboard-Support-SJG-N-R1 left.stl, PET-Keyboard-Support-SJG-N-R1 right.stl]
2025-11-02 fix the two 3.0A issues (temporarily)
    [petkn-CuBottom.gbr, petkn-CuTop.gbr, petkn-EdgeCuts.gbr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]
2025-11-05 refactor LED ctrl into multiple files
2025-11-05 led controller understands single keypress
2025-11-05 kbd ctrl sends led commands
2025-11-06 fix LED address decoding
    [i2c.c]
2025-11-06 use raw key presses instead of mapped ones in I2C, so HW mapping works
2025-11-22 fix hand in i2c code
    [i2c.c]
2026-01-02 make shift lock / reset work, with led display; fix hang
    [i2c.c, kbdhw.c]
2026-01-05 improved error handling, hopefully fixing the hangs
    [i2c.c]
2026-01-06 work on LED i2c
2026-01-06 allow sending kprogs from I2C
2026-01-30 first run on r3.1
    [connector.kicad_sch, joystick.kicad_sch, keys.kicad_sch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]
2026-03-06 new key caps
    [Commodore PET caps for N keyboard fine slices(1).stl, Commodore PET caps for N keyboard fine slices(2).stl, Commodore PET caps for N keyboard fine slices(3).st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]
2026-03-06 working on new layout
    [connector.kicad_sch, ledctrl.kicad_sch, petkn.kicad_pcb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]
2026-03-08 final layout, production files for 3.1A
    [BOM-petkn.csv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]
2026-03-08 fixed position file
    [CPL-petkn-fixed.csv]
2026-04-05 add orientation marker for backlight LEDs and move to 3.1B
    [BOM-petkn.csv, connector.kicad_sch, joystick.kicad_sch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]
2026-04-18 add demo program for the key leds
2026-05-03 make kbd controller backward compat to rev 3.0 board; fix shift lock after reset bug

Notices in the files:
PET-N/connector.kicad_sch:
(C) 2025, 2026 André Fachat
